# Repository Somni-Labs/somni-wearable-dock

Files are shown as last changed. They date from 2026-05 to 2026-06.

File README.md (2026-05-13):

# Wearable Charging Stand

3D printable unified charging dock for 6 non-Apple wearable devices, with a hidden internal slim 4-port USB-C wall charger and cable management.

## Devices

| Slot | Device | Charger Type | Cradle Style |
|---|---|---|---|
| 1 | Omi Pendant (DevKit 2) | Pogo-pin direct charge | Six-sided diamond pocket (41×40mm) |
| 2 | Ultrahuman Ring Air | USB-C puck dock (~50mm) | Circular cup |
| 3 | Even Realities R1 Ring | NFC magnetic dock (45mm) | Circular cup |
| 4 | Even Realities G2 Glasses | USB-C case (170×75mm) | Rectangular shelf |
| 5 | Omi Developer Edition | Triangle pendant charger | Triangular pocket |
| 6 | Mudra Link Wristband | Proprietary cable | Rectangular pocket |

## Design Features

- **Single AC input** — one cable from the wall to the internal multi-port USB-C charger
- **Hidden cable routing** — channels inside the base route cables from the charger to each cradle
- **Bottom access panel** — removable cover (v2) / removable top tray (v1) to install the charger and manage cables
- **Cradle-per-charger** — each device's existing charger sits in a fitted pocket; cables route through pass-through holes
- **Rubber feet recesses** — stick-on feet for grip and airflow
- **Clean desktop aesthetic** — dark PETG, rounded edges, no visible cables

## Design Files

| File | Description |
|---|---|
| `designs/v1-charging-stand.py` | Two-part snap-fit design (bottom tray + top tray), with iPad slot |
| `designs/v2-charging-stand.py` | Single-piece design with bottom access panel |
| `stl/` | Exported STL files ready for slicing |

## Dimensions

All cradle dimensions are parametric and defined at the top of the design file. After a test print, measure your actual chargers and adjust the `TOL` (tolerance) and individual device dimensions as needed.

**Note:** Some charger dimensions are estimated from product photos since manufacturers don't publish exact specs. Adjust after test fitting:
- Ultrahuman Ring charger: estimated ~50mm diameter puck
- Even R1 charger: measured 45mm diameter × 12mm height dock
- Even G2 case: measured 170×75×30mm
- Omi DevKit 2: measured 41×40×13mm six-sided diamond pendant

## Print Settings

- **Material:** PETG (dark grey/black recommended)
- **Layer height:** 0.2mm
- **Infill:** 20%
- **Walls:** 3 perimeters
- **Supports:** Minimal (cradle cups print fine without)

## Internal USB-C Charger

The stand houses a **slim flat 4-port USB-C wall charger** inside the base, centered under the G2 case shelf. A single AC cable feeds the charger from behind; short USB-C cables route from each output to the cradles through the internal channels.

**Recess dimensions:** 88 × 55 × 17 mm (W × D × H), includes ~3 mm tolerance per side.

### Why a wall charger instead of a USB-C data hub

A passive USB-C "hub" shares a single upstream PD profile across all downstreams, so it can't reliably negotiate independent charging for 6 wearables that each expect their own power profile. A multi-port USB-C wall charger contains independent regulators per port — the architecture each wearable's bundled charger expects.

### Recommended charger class

Look for a **slim flat 4-port USB-C wall charger** at ~30–35 W total with a mix of USB-C and USB-A outputs (typically 1× USB-C PD + 1× USB-C + 2× USB-A). The recess accepts the common "flat brick" form factor (≈83 × 44 × 14 mm).

- ✅ **Fits:** BUDI 34W 4-Port Flat USB-C Wall Charger (slim profile, 20W PD on the primary USB-C port). Any flat 4-port charger within the recess envelope and ≥30 W total works.
- ❌ **Does not fit:** UGREEN Nexode 65W/100W and similar GaN multi-port chargers — they are roughly 65 × 65 × 33 mm because they contain a full wall-AC supply in a cube form factor.
- ❌ **Do not use** a USB-C data hub (CalDigit, Anker thin hubs, etc.) for power splitting — they cannot independently power-deliver to multiple downstreams.

Total wearable load is well under 30 W (each device draws ≤5 W), so a 30–35 W charger has headroom even when everything is on the dock simultaneously.

## Editing

Designs use [CadQuery](https://cadquery.readthedocs.io/) and render via [cadquery-server](https://github.com/robodk/cadquery-server).

```bash
pip install cadquery cadquery-server
cq-server /path/to/designs/
```

## License

MIT

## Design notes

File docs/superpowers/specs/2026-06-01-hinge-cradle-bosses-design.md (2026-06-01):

# Hinge Cradle Bosses for Device Tray

**Date:** 2026-06-01  
**Status:** Approved

## Problem

The tilt plate hinge barrel sockets in `build_device_tray()` are 3.6mm cylindrical cuts positioned at the pocket edge (Y = pocket front face). The pocket cut already removed material from that Y inward, so the sockets only create a ~1.8mm-deep half-pipe scallop in the pocket wall — invisible on a 0.3mm layer-height FDM print and non-functional as a hinge cradle.

The cable notch forward of each pocket further erodes the wall at the same Z range as the sockets, making the problem worse.

## Solution

Replace the cylindrical socket cuts with **raised U-channel cradle bosses** — solid rectangular blocks unioned onto the pocket's front interior wall, with a semicircular channel cut into the top for the hinge barrel to drop into from above.

## Dimensions

### Boss Body
- **Width (X):** `HINGE_BARREL_L + 1.0` = 9.0mm (0.5mm wall each side of 8mm barrel)
- **Depth (Y):** 2.5mm (protrudes into pocket from front wall face)
- **Height (Z):** `HINGE_BARREL_OD + 1.5` = 4.5mm (barrel diameter + 1.5mm retention wall above)

### U-Channel
- **Radius:** `(HINGE_BARREL_OD + HINGE_SOCKET_TOL * 2) / 2` = 1.8mm
- **Open top** — barrel drops in from above
- **Axis:** parallel to X (same as barrel axis)
- **Length:** full boss width (9mm)

### Positioning Per Pocket
- **Y:** pocket front interior wall face (`pocket_center_y - pocket_size/2`), boss extends +Y into the pocket by 2.5mm
- **Z:** bottom of boss at pocket floor level (`STAND_H - CRADLE_DEPTH`), channel center at `pocket_floor + HINGE_BARREL_OD/2 + 0.5`
- **X:** same barrel spacing as existing tilt plates:
  - UH: 20mm apart (±10mm from pocket center X)
  - R1: 8mm apart (±4mm from pocket center X)
  - Omi: 8mm apart (±4mm from pocket center X)

## Assembly

1. Drop tilt plate into pocket — barrels facing front (-Y)
2. Barrels settle into U-channels by gravity
3. Push rod T-head engages captured slot on tilt plate underside
4. Push rod keeps tilt plate seated; U-channel walls prevent barrel pop-out during tilt

## What Changes

- `build_device_tray()`: Remove 6 cylindrical barrel socket cuts, add 6 U-channel cradle boss unions + channel cuts
- Add new constants: `HINGE_BOSS_DEPTH`, `HINGE_BOSS_H`, `HINGE_BOSS_W`
- Re-export device tray STL
- Re-slice device tray

## What Doesn't Change

- Tilt plates (barrel geometry unchanged)
- Push rods
- Top tray
- Bottom tray
- Any other part

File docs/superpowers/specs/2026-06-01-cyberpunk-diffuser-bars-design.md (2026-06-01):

# Cyberpunk Diffuser Bars — Design Spec

## Summary

Add subtle fragmented horizontal light bars recessed into the exterior walls of the bottom tray. Each bar is a shallow recess cut from the outside, leaving a 1.0mm thin-wall diffuser that glows when backlit by the existing U-shaped WS2812B LED strip. The pattern is asymmetric and restrained — cyberpunk but not overwrought.

## Constraints

- **Recess depth:** 1.5mm into the 2.5mm wall (leaves 1.0mm diffuser skin)
- **Bar height:** 3mm tall each
- **Minimum spacing:** 6mm solid wall between adjacent bars
- **Edge clearance:** No cuts within 5mm of top edge (snap clips at Z=50) or bottom edge (floor at Z=0)
- **Usable Z range:** Z=6 to Z=44
- **No new LED routing:** Uses existing U-shaped strip (left, front, right walls)
- **Sharp rectangular edges:** No fillets on bar recesses (cyberpunk aesthetic)
- **Structural integrity:** Narrow bars with wide solid sections between them preserve wall rigidity

## Layout

### Left wall (-X side, ~175mm along Y)

3 bars, staggered heights:

| Bar | Length | Z center | Y offset | Notes |
|-----|---|---|---|---|
| 1 | 60mm | Z=15 | toward front | longest bar, low placement |
| 2 | 25mm | Z=30 | toward front | short, high |
| 3 | 40mm | Z=10 | toward rear  | medium, lowest |

### Right wall (+X side, ~175mm along Y)

3 bars, asymmetric to left wall:

| Bar | Length | Z center | Y offset | Notes |
|-----|---|---|---|---|
| 1 | 45mm | Z=25 | centered | medium, mid-height |
| 2 | 20mm | Z=12 | toward rear  | shortest, low |
| 3 | 55mm | Z=35 | toward front | long, highest |

### Front wall (-Y side, ~240mm along X)

Logo stays at Z=20, center. Two short accent bars flanking it:

| Bar | Length | Z center | X offset | Notes |
|-----|---|---|---|---|
| 1 | 30mm | Z=35 | near left edge  | above logo height |
| 2 | 25mm | Z=12 | near right edge | below logo height |

## Implementation

All cuts happen in `build_bottom_tray()` after the existing LED channel/slot code. Each bar is a `cq.Workplane("XY")` box cut from the exterior wall face inward by 1.5mm, 3mm tall, at the specified length and position.

### Parameters (new constants)

```python
# --- Cyberpunk diffuser bars ---
CYBER_BAR_H = 3            # bar height (Z)
CYBER_BAR_DEPTH = 1.5      # recess depth (leaves 1.0mm diffuser)
CYBER_DIFFUSER_T = 1.0     # remaining wall thickness (diffuser skin)
```

### No changes to

- LED strip channel geometry
- LED exit slots at base
- Backlit logo
- Top tray, device tray, or any other part
- QuinLED / ESP32 / servo mounts
- Snap clips or structural features

## Verification

After export + push + cadquery-server restart, verify:
1. Bars visible as recesses on exterior walls in 3D preview
2. No interference with interior components (LED channel, mounts, wiring grooves)
3. Wall integrity — solid wall remains between and around all bars
4. Logo unobstructed on front wall

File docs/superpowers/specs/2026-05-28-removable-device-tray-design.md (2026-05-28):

# Removable Device Tray

Separate the four front-row wearable device pockets (UH Ring, R1 Ring, Omi pendant, Mudra pole socket) from the top tray body into a standalone drop-in tray. The tray prints right-side up with no supports and drops into a rectangular cutout in the top tray.

## Motivation

The top tray currently contains all four front-row device pockets molded directly into its body. When printed flipped (required because the top tray sits on the bottom tray), these pockets create deep overhangs that require heavy support material, long print times, and risk spaghetti failures. Separating the device zone into its own tray eliminates these problems:

- Device tray prints right-side up -- zero supports
- Top tray flipped print becomes much simpler (single rectangular cutout instead of four complex pockets)
- Device tray can be reprinted independently if devices change
- Faster iteration on pocket geometry without reprinting the entire top tray

## Assembly

6 parts total (was 5):

1. Bottom tray
2. Top tray (with rectangular device tray cutout)
3. **Device tray (new)** -- drops into top tray cutout
4. Mudra pole -- snaps into device tray (was top tray)
5. iPad cover plate
6. iPad back wall

## Device Tray Geometry

### Footprint

The tray spans all four front-row devices:

- **X span**: UH left edge (X = -102) to Mudra shelf right tip (X = +109), plus WALL (2.5mm) on each side = **~220mm wide**
- **Y span**: Front wall inner face (Y = -85) to rear edge of deepest pocket plus margin = **~55mm deep**
- **Z height**: 15mm (from Z = 43 to Z = 58, i.e., SPLIT_Z + LID_FLOOR to STAND_H)

Exact dimensions will be computed from the existing SLOT_POSITIONS, device pocket sizes, and Mudra shelf extent during implementation. The values above are estimates for planning.

### Contents (moved from top tray)

Everything device-specific moves to the device tray:

- **UH Ring pocket** -- square cutout (41x41mm), rounded corners, USB-C front wall notch, floor cable hole, hinge barrel sockets
- **R1 Ring pocket** -- circular cutout (32mm dia), USB-C front wall notch, floor cable hole, hinge barrel sockets
- **Omi pocket** -- six-sided diamond cutout, USB-C front-left notch, floor cable hole, hinge barrel sockets
- **Mudra pole socket** -- rectangular through-hole (20.6x22.6mm) with snap engagement pockets on underside, cable pass-through
- **Push rod slots** -- 4x rectangular through-holes at SERVO_Y for servo actuators
- **Cable pass-through holes** -- USB-C sized holes through tray floor for each device

### Front wall interface

The device tray's front edge butts against the inner face of the top tray's front wall. Cable exit notches in the tray's front edge align with matching slots in the top tray wall, creating a continuous cable path:

```
device pocket --> tray front notch --> top tray front wall slot --> exterior
```

The front wall cable slots for UH, R1, and Omi remain in the top tray's front wall. The device tray has matching open notches on its front edge.

## Top Tray Modifications

### Rectangular cutout

A single rectangular opening replaces all four device pockets. Sized to match the device tray outer dimensions plus 0.3mm clearance per side (SNAP_TOL).

### Perimeter ledge (3-sided)

A 2.5mm wide ledge (WALL thickness) around the cutout at Z = SPLIT_Z + LID_FLOOR (Z = 43). The ledge runs on three sides:

- **Left**: cutout wall
- **Right**: cutout wall  
- **Rear**: cutout wall

The **front side has no ledge** -- the top tray's front wall acts as containment. The tray's front edge sits flush against the wall's inner face.

### Removed geometry

All device pocket cuts, hinge barrel sockets, push rod slots (in the device zone), Mudra socket, and Mudra snap pockets are removed from `build_top_tray()`. The LID_FLOOR remains but gets the device tray cutout instead of individual through-holes for the front-row devices.

### Retained geometry

- Outer shell and walls (including front wall with backlit logo)
- Snap-fit clips for bottom-to-top tray connection
- G2 glasses case pocket (rear row)
- iPad channel, tunnel, blade slot, cover plate rails, front lip
- AC cable pass-through (left wall)
- Spare USB exit (back wall)
- Front wall cable slots (UH, R1, Omi USB-C exits)
- LID_FLOOR (with device tray cutout)
- G2 cable hole, G2 LCD window, iPad cable hole, iPad blade slot re-cuts

## Retention Mechanism

**Drop-in friction fit** -- no clips, no fasteners.

- 0.3mm clearance per side (SNAP_TOL) between tray walls and cutout walls
- Gravity holds the tray down on the ledge
- Front wall contains the tray in -Y
- Cutout walls contain in +/-X and +Y
- Top surface flush at Z = STAND_H (58mm)

If the fit is too loose in practice, small detent bumps (like the iPad wall's IPAD_DETENT_H = 0.6mm) can be added later.

### Mudra pole snap engagement

The Mudra pole's snap hooks currently engage pockets cut into the underside of the top tray at Z = SPLIT_Z - 3mm. With the device tray, the pole snaps into the tray instead. The snap engagement pockets move to the device tray's underside. Since the tray floor is at Z = 43 (DTRAY_FLOOR_Z), the pockets cut upward into the tray body from below. The tray has 15mm of material -- more than enough for the 3mm pocket depth. The cutout ledge in the top tray must have a matching clearance notch so the snap hooks don't collide with the ledge when the tray drops in.

## Printing

### Device tray

- Prints **right-side up** (flat floor on build plate, pockets facing up)
- **No supports needed** -- all pockets are open-top
- **No brim needed** -- solid rectangular base, good adhesion
- Estimated height: 15mm
- Fast print, simple geometry

### Top tray (modified)

- Still prints **flipped** (Z=58 on build plate)
- Dramatically simpler -- one rectangular cutout replaces four complex pocket overhangs
- Support material drops significantly (only G2 pocket + iPad channel overhangs remain)
- Shorter print time

## Export and Slicing

### New function

`build_device_tray()` in `designs/v1-charging-stand.py` -- builds the tray at its assembly position (Z = 43 to Z = 58), exported translated down to Z = 0 for printing.

### Export script

`export_charging_stand.py` gets a new entry:
- `v1-charging-stand-device-tray.stl` / `.step`
- Translated to Z = 0, no flip needed

### Slicer job

New `k8s/slice-device-tray.yaml`:
- No supports, no brim
- 70C bed, 215/220C extruder
- Fan off first 3 layers, 80% max
- sed guard for M106 S255 -> S204
- No support validation check (supports not needed)

### Ghost visualization

The device tray should be included in `build_ghost_components()` or shown as a distinct object in cadquery-server preview for assembly visualization.

## Constants

New constants to add:

```python
# --- Removable device tray ---
DTRAY_TOL = SNAP_TOL          # 0.3mm clearance per side
DTRAY_LEDGE = WALL            # 2.5mm ledge width
DTRAY_FLOOR_Z = SPLIT_Z + LID_FLOOR  # 43mm -- bottom of device tray
```

Width and depth computed dynamically from SLOT_POSITIONS and device dimensions.

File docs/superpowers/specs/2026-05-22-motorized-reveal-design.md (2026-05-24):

# Motorized Wearable Reveal System

**Date**: 2026-05-22
**Status**: Approved

## Overview

Add a motorized "reveal" mechanism to the charging stand: 4x SG90 micro servos in the bottom tray push wearable cradles upward through the top tray at a 30-degree tilt angle when triggered. Replace the small LED driver pocket with a full QuinLED-Dig-Uno WLED controller mount. Update the ESP32 mount for pin-header boards (slot-cradle instead of screw standoffs). Add a VL53L0X proximity sensor for hands-free activation. Add ghost visualization objects for all internal components in the cadquery-server preview.

## 1. SG90 Servo Mounts (4x)

**Servo:** SG90 micro servo (23mm x 12.2mm x 22.7mm body, 32.4mm with mounting ears, 4mm shaft height, ~250mA under load at 5V).

**Orientation:** Upright, shaft pointing UP (+Z). The servo horn connects to a push rod that extends through the top tray floor to tilt the wearable cradle.

**Y position (all 4 servos):** Y = -37mm (fixed row). This places them 12.5mm behind the front-row device centers (Y = -49.5mm) and 5.9mm clear of the charger bay front edge (Y = -25mm).

**X positions (matching device columns):**

| Servo | Device | X (mm) |
|---|---|---|
| 1 | Ultrahuman Ring | -81 |
| 2 | Even R1 | -27 |
| 3 | Omi DevKit | +27 |
| 4 | Mudra Pole | +73 |

**Inter-servo spacing:** 54mm between servos 1-2 and 2-3 (21.6mm gap between ears), 46mm between servos 3-4 (13.6mm gap between ears). All clear.

**Vertical placement:**
- Servo base sits on floor: Z = BASE_H (3mm)
- Servo body top: Z = 3 + 22.7 = 25.7mm
- Servo shaft/horn top: Z = 3 + 26.7 = 29.7mm
- Split plane: Z = 41mm (11.3mm clearance above servo)
- Push rod extends from horn through the 11.3mm gap, through the top tray floor (17mm), to the device cradle

**Mount geometry (per servo):**
- Rectangular pocket in the floor: 34mm x 14mm x 5mm deep (body drops in, ears rest on pocket rim)
- The pocket is 34mm wide to accommodate the 32.4mm ear span + tolerance
- 2x M2 screw posts: 5mm tall, centered on ear screw holes (holes are 27.5mm apart, centered on body)
- Posts are 2.5mm outer diameter with 1mm pilot holes for M2 self-tapping screws
- Open top — servo drops in from above, screws secure the ears

**Clearances:**
- Servo body (12.2mm deep in Y) centered at Y=-37: front edge at Y=-43.1, rear edge at Y=-30.9
- Front-row device pockets start at ~Y=-49.5; smallest gap is Mudra socket rear edge at Y=-38.2 — 4.9mm clear of servo front edge
- Charger bay front at Y=-25 — 5.9mm clear of servo rear edge

## 2. Push Rod Slots (Top Tray)

Each servo needs a slot through the top tray floor for the push rod to pass through and actuate the wearable cradle.

**Slot dimensions:** 4mm wide x 12mm long (oriented along Y), centered at the servo shaft X position, offset from device center by the tilt geometry.

**Push rod geometry:**
- Rigid rod (printed or metal wire), ~2mm diameter
- Connects servo horn to underside of cradle tilt plate
- Rod length: ~28mm (from servo horn at Z=29.7 to cradle floor at Z=STAND_H - cradle_depth)

**Slot positions (in top tray floor, at Z = SPLIT_Z):**

| Slot | X (mm) | Y (mm) | Notes |
|---|---|---|---|
| UH Ring | -81 | -37 | Behind ring pocket |
| R1 Ring | -27 | -37 | Behind disc pocket |
| Omi | +27 | -37 | Behind diamond pocket |
| Mudra | +73 | -37 | Behind pole socket |

## 3. Tilt Mechanism (Front-Row Cradles)

**Concept:** Each front-row cradle (UH Ring, R1, Omi) gets a hinge along its rear edge. The push rod pushes the front edge up, tilting the cradle 30 degrees toward the user. When the servo retracts, the cradle drops back flush.

**Hinge slot:** A narrow gap (0.8mm) cut across the rear edge of each cradle pocket at the floor level. This acts as a living hinge — thin enough to flex but thick enough to survive repeated cycles.

**Tilt angle:** 30 degrees. At 30 degrees with a cradle depth of ~20mm, the front edge rises sin(30) x 20 = 10mm — a subtle but noticeable reveal.

**Mudra pole (servo 4):** The mudra servo pushes the pole straight UP (vertical rise, no tilt). The pole already sits in a through-socket; the push rod lifts it 15mm to present the wristband at a more accessible height. A small collar on the push rod prevents the pole from lifting out completely.

**Implementation note:** The tilt mechanism is a future enhancement that requires careful living-hinge design and push-rod linkage tuning. For the initial build, the servo mounts, push rod slots, and wiring are all installed, but the cradles remain fixed. The servos can be tested independently (horn rotation visible through the slots) before adding the tilt plates in a later iteration.

## 4. QuinLED-Dig-Uno Mount (Replaces Driver Pocket)

**Board:** QuinLED-Dig-Uno v3 (50mm x 50mm PCB, ~30mm tall with components). WLED-compatible ESP8266-based LED controller with onboard level shifting, 2x LED outputs, fused 5V input.

**Location:** Front-right corner of the bottom tray interior (mirrors ESP32 on the front-left). Symmetric layout.

**Position (board center):**
- X = +STAND_W/2 - WALL - 50/2 = +117.5 - 25 = +92.5mm
- Y = -STAND_D/2 + WALL + 50/2 = -85 + 25 = -60mm

**Mount geometry:**
- 4x M2 standoff posts: 3mm diameter, 3mm tall, at QuinLED mounting hole positions (4mm inset from each corner, on a 42mm x 42mm square pattern)
- Two cradle walls: right side (against outer wall) and front side (against front wall), 1.5mm thick, 8mm tall
- Open on left and rear sides for cable access
- The existing cable winding posts in the right-side pocket at Y < -35mm are removed (they overlap the QuinLED footprint). Posts at Y > -35mm remain.

**Power input:** 5V DC from VanBon USB-A port via USB cable. The QuinLED has a screw terminal for 5V input (or can be powered via its own USB port).

**LED strip connection:** QuinLED LED output → WS2812B strip DIN. Wire routes through a floor groove from QuinLED to the right-wall LED channel start.

**Clearances:**
- Board top: 3 + 3 + 30 = 36mm; SPLIT_Z = 41mm — 5mm clearance
- Board left edge at X = 92.5 - 25 = 67.5mm; charger bay right edge at X = 73mm — 5.5mm overlap in X but separated by 35mm in Y (charger at Y=15, QuinLED at Y=-60)
- Mudra servo at X=73, Y=-37: 19.5mm away in X from QuinLED center, no physical overlap

**Replaces:** The old LED driver pocket (22mm x 16mm x 8mm at X=-103, Y=-13) is REMOVED. The QuinLED-Dig-Uno has onboard level shifting, eliminating the need for a separate driver board.

## 5. Updated ESP32 Mount (Pin-Header Slot-Cradle)

**Board:** ESP32-DevKitC V4 with pre-soldered pin headers. Same 55x28mm PCB, but total height ~23mm with headers (~8.5mm pin length below PCB + ~12mm components above).

**Location:** Same front-left corner position (center X=-103, Y=-57).

**Mount change:** Replace the 4 screw standoff posts with a slot-cradle design. The DevKitC V4 doesn't have standard mounting holes; with pin headers, the board rides on the header pins which sit in grooves.

**Slot-cradle geometry:**
- 2 parallel raised rails running along Y (board length direction)
- Rail dimensions: 56mm long (board + 1mm tolerance) x 5mm wide x 10mm tall
- Rail spacing: 25.4mm center-to-center (matching standard 0.1" header pitch for 28mm-wide board)
- Rail X positions: X = -103 +/- 12.7mm = X=-115.7 and X=-90.3
- Each rail has a 3.5mm wide x 8.5mm deep groove on its inner face (the pin headers ride in these grooves)
- Board slides in from the rear (+Y direction) — front end is closed (retaining wall), rear end is open for insertion
- Retaining tab: 2mm tall bump at the front end of each groove to prevent the board from sliding out

**Cradle walls:** Keep the existing left-side and front-side cradle walls (1.5mm thick, 6mm tall) for lateral support above the PCB level.

**USB port access:** Same 12mm x 8mm slot through the front wall, repositioned for the higher board position: Z center = BASE_H + 10 (rail height) + 4mm (USB port center on PCB) = 17mm.

**Clearances:**
- Board top: 3 + 10 + 12 = 25mm; SPLIT_Z = 41mm — 16mm clearance
- Left rail at X=-115.7: inner wall at X=-117.5 — 1.8mm clear (tight but printable)
- Right rail at X=-90.3: charger bay left at X=-73 — 17.2mm clear

## 6. VL53L0X Proximity Sensor Mount

**Sensor:** VL53L0X Time-of-Flight laser ranging module (13mm x 18mm breakout board, I2C, 3.3V, range 30-1200mm). Detects hand approach to trigger the reveal animation.

**Location:** Front wall interior, to the right of the ESP32 mount.

**Position (sensor center):**
- X = _esp_x + ESP32_W/2 + 5 + 9 = -103 + 14.5 + 5 + 9 = -74.5mm
- Y = -STAND_D/2 + WALL + 9 = -85 + 9 = -76mm (against front wall)
- Z = BASE_H + 5 = 8mm (low, pointing forward through front wall)

**Mount geometry:**
- Small clip bracket: two 1.5mm thick x 5mm tall walls on left and right sides of the sensor, spaced 14mm apart (13mm board + 1mm tolerance)
- Sensor drops in from above, held by friction

**Front wall window:**
- Rectangular opening through the front wall: 8mm wide x 6mm tall
- Centered on the sensor's laser emitter/detector position
- Allows the ToF laser to "see" through the wall to detect approaching hands

**Wiring:** I2C (SDA, SCL) + 3.3V + GND from ESP32. 4 wires route through a floor groove from sensor position to ESP32.

## 7. Servo Wiring Channels

**Channel dimensions:** 8mm wide x 4mm deep grooves in the bottom tray floor. Wider than the existing 6mm data wire grooves because servo cables are thicker (3-wire bundles).

**Channel layout:**
- **Main trunk:** Runs along X at Y=-37 (the servo row), connecting all 4 servo positions. Length: from X=-81 to X=+73 = 154mm.
- **ESP32 spur:** From the main trunk at X=-81, turns toward the ESP32 at X=-103, Y=-57. L-shaped: 22mm along X then 20mm along Y.
- **QuinLED spur:** From the main trunk at X=+73, turns toward the QuinLED at X=+92.5, Y=-60. L-shaped: 19.5mm along X then 23mm along Y.

**Wire management clips:** Arch bridges every ~40mm along the main trunk. Same design as the existing cable clips (14mm wide, 8mm tall, 2.5mm thick arch walls) but spaced along the servo wire trunk.

Clip positions on main trunk (Y=-37):
- X = -81 (servo 1)
- X = -54 (midpoint 1-2)
- X = -27 (servo 2)
- X = 0 (midpoint 2-3)
- X = +27 (servo 3)
- X = +50 (midpoint 3-4)
- X = +73 (servo 4)

Note: Some of these may overlap existing front-row cable clips (at Y=-37.5). The implementation should check for overlap and skip duplicates.

## 8. Ghost Visualization Objects

**Pattern:** Follow the somni-humidifier `build_components()` pattern. Create a `build_ghost_components()` function that returns a dict of `{name: (solid, (r, g, b, alpha))}` tuples. Display them with `show_object()` in the build section using translucent colors.

**Components to visualize:**

| Component | Color | RGBA | Shape |
|---|---|---|---|
| ESP32 board | Blue PCB | (0.1, 0.35, 0.7, 0.85) | 55x28x12mm box at mount position |
| QuinLED-Dig-Uno | Green PCB | (0.15, 0.55, 0.15, 0.85) | 50x50x30mm box at mount position |
| SG90 servo x4 | Orange | (0.85, 0.45, 0.1, 0.8) | 23x12.2x22.7mm box + 32.4mm ear plate at each servo position |
| LED strip | Bright green | (0.2, 1.0, 0.3, 0.7) | 10mm x 2mm cross-section, U-shaped path following LED channel |
| VL53L0X sensor | Light blue | (0.3, 0.3, 0.8, 0.85) | 13x18x3mm box at sensor position |
| VanBon charger | Dark gray | (0.3, 0.3, 0.3, 0.5) | 134x68x33mm box in charger bay |
| Servo wires | Yellow | (0.9, 0.85, 0.1, 0.6) | 3mm diameter path following wire channels |

**Display loop (in BUILD AND DISPLAY section):**
```python
ghosts = build_ghost_components()
for comp_name, (comp_solid, comp_color) in ghosts.items():
    show_object(comp_solid, name=f"ghost_{comp_name}",
                options={"color": comp_color})
```

**Implementation:** Each ghost is a simple CadQuery box or extruded shape placed at the component's world-coordinate position. No boolean operations with the tray geometry — these are independent overlay objects for visualization only.

## 9. Constants

New and updated parametric constants:

```python
# --- SG90 micro servo mount ---
SG90_BODY_L = 23          # body length (X)
SG90_BODY_W = 12.2        # body width (Y)
SG90_BODY_H = 22.7        # body height (Z, not including shaft)
SG90_EAR_W = 32.4         # total width with mounting ears
SG90_EAR_T = 2.5          # ear thickness (Z)
SG90_SHAFT_H = 4          # shaft + horn height above body
SG90_SCREW_SPACING = 27.5 # distance between M2 screw holes on ears
SG90_SCREW_D = 2          # M2 screw hole diameter
SERVO_Y = -37             # Y position for all servo mounts
SERVO_POCKET_W = 34       # pocket width (ears + tolerance)
SERVO_POCKET_D = 14       # pocket depth in Y (body + tolerance)
SERVO_POCKET_H = 5        # pocket depth in Z (into floor)
SERVO_POST_H = 5          # screw post height
SERVO_POST_OD = 2.5       # screw post outer diameter
SERVO_PILOT_D = 1.0       # pilot hole for M2 self-tapping

# --- Push rod slots (top tray) ---
PUSH_ROD_SLOT_W = 4       # slot width (X)
PUSH_ROD_SLOT_L = 12      # slot length (Y)

# --- QuinLED-Dig-Uno mount (replaces DRIVER_* constants) ---
QLED_W = 50               # board width (X)
QLED_D = 50               # board depth (Y)
QLED_H = 30               # board height (Z, tallest component)
QLED_STANDOFF_H = 3       # standoff post height
QLED_STANDOFF_D = 3       # standoff post diameter
QLED_MOUNT_INSET = 4      # M2 hole inset from board edge
QLED_MOUNT_PITCH = 42     # M2 hole spacing (50 - 2*4)
QLED_CRADLE_H = 8         # cradle wall height
QLED_CRADLE_T = 1.5       # cradle wall thickness

# --- ESP32 mount (updated for pin headers) ---
ESP32_L = 56              # board length + tolerance (along Y)
ESP32_W = 29              # board width + tolerance (along X)
ESP32_H = 23              # total height with pin headers
ESP32_PIN_H = 8.5         # pin header length below PCB
ESP32_RAIL_H = 10         # slot-cradle rail height
ESP32_RAIL_W = 5          # rail width
ESP32_RAIL_PITCH = 25.4   # center-to-center of rail grooves (0.1" header pitch)
ESP32_GROOVE_W = 3.5      # groove width (2.54mm header + 1mm tolerance)
ESP32_GROOVE_D = 8.5      # groove depth (full pin length)
ESP32_CRADLE_H = 6        # cradle wall height (above rail top)
ESP32_CRADLE_T = 1.5      # cradle wall thickness
ESP32_USB_SLOT_W = 12     # USB port slot width through front wall
ESP32_USB_SLOT_H = 8      # USB port slot height through front wall

# --- VL53L0X proximity sensor ---
PROX_W = 13               # sensor board width (X)
PROX_D = 18               # sensor board depth (Y)
PROX_H = 3                # sensor board height (Z)
PROX_CLIP_H = 5           # clip bracket height
PROX_CLIP_T = 1.5         # clip bracket thickness
PROX_WINDOW_W = 8         # window width through front wall
PROX_WINDOW_H = 6         # window height through front wall

# --- Servo wiring channels ---
SERVO_WIRE_W = 8          # servo wire channel width
SERVO_WIRE_D = 4          # servo wire channel depth
SERVO_CLIP_SPACING = 40   # arch clip spacing along trunk (approximate)
```

## 10. Removed Constants

The following constants are REMOVED (replaced by QuinLED mount):
```python
# REMOVED — replaced by QLED_* constants
# DRIVER_L = 22
# DRIVER_W = 16
# DRIVER_H = 8
# DRIVER_STANDOFF_H = 2
# DRIVER_STANDOFF_D = 2
```

The following ESP32 constants are REMOVED (replaced by slot-cradle design):
```python
# REMOVED — replaced by ESP32_RAIL_*, ESP32_GROOVE_* constants
# ESP32_STANDOFF_H = 2
# ESP32_STANDOFF_D = 3
```

## 11. Print Impact

**Bottom tray changes:**
- Servo pockets: 4x subtractive cuts — slight reduction in print time
- Servo screw posts: 8x small cylinders — negligible material
- QuinLED mount: replaces small driver pocket with larger cradle — slight increase
- ESP32 slot-cradle: replaces standoff posts with rails — roughly equivalent material
- Servo wire channels: subtractive — slight reduction
- Wire arch clips: 7x small arches — negligible
- Proximity sensor bracket: 2 small walls — negligible
- Front wall window: subtractive — negligible
- **Net impact: approximately zero additional print time**

**Top tray changes:**
- 4x push rod slots: subtractive cuts through floor — negligible
- **Net impact: trivially less print time**

## 12. Files Changed

| File | Change |
|---|---|
| `designs/v1-charging-stand.py` | Add servo/QuinLED/sensor constants; replace ESP32 standoffs with slot-cradle and driver pocket with QuinLED mount in `build_bottom_tray()`; add servo mounts, servo wire channels, proximity sensor bracket, push rod slots; add `build_ghost_components()` function; update display section |
| `CLAUDE.md` | Document motorized reveal, QuinLED, updated ESP32 mount, proximity sensor, ghost objects |

## 13. Trigger Mechanism (Software — Future)

The ESP32 handles all trigger logic (not part of the CadQuery geometry, but informs the hardware layout):

- **Proximity:** VL53L0X detects hand within 300mm → triggers reveal animation
- **Button:** Capacitive touch pad on top tray surface (future addition)
- **App:** MQTT/HTTP command from phone via WiFi
- **Schedule:** Time-based (morning routine reveal)

The ESP32 drives all 4 servos via GPIO pins (GPIO 13, 14, 25, 26). PWM signal, no additional driver board needed for SG90 servos.

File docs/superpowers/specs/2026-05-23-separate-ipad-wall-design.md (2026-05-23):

# Separate iPad Back Wall Insert

**Date:** 2026-05-23
**Status:** Approved
**Trigger:** Top tray print cancelled after 10 hours — the 60mm iPad back wall makes the flipped top tray ~77mm tall, consuming massive print time for a simple vertical wall

## Problem

The iPad back wall (`IPAD_BACK_H = 60mm`) is unioned directly onto the top tray. When the top tray is flipped for printing (pocket surface face-down), the wall becomes the tallest feature — 60mm of vertical wall printed first, before the actual tray body even begins. This makes the top tray ~77mm tall on the build plate, adding hours of print time for geometry that is structurally just a flat slab.

## Solution

Extract the iPad back wall into a separate slide-in piece, using tongue-and-groove rails — the same pattern already used for the iPad cover plate. The wall prints flat on its back (4mm tall, ~15 minutes) and slides into the top tray from the side.

### 1. Top Tray Modifications (`build_top_tray()`)

**Remove:** The `ipad_back` union block — the 60mm tall back wall currently built at `Z = STAND_H`, centered at `Y = STAND_D/2 - IPAD_BACK_THICK/2`, width `IPAD_SLOT_W + 10`, thickness `IPAD_BACK_THICK` (4mm).

**Keep:** The front lip (`ipad_lip`) remains on the top tray — 5mm tall, provides iPad retention even without the wall installed.

**Add:** A tongue-and-groove rail along the rear edge of the top tray top surface where the wall base sits.

**Rail groove dimensions:**
- Position: top surface of tray at the rear edge, centered on `Y = STAND_D/2 - IPAD_BACK_THICK/2` (same Y as the old wall)
- Groove width (X): `IPAD_SLOT_W + 10 + 2` (full wall width + exits both sides for slide-in)
- Groove depth (Y): 3mm (into the tray surface)
- Groove height (Z): 3mm (cut down from the top surface)
- Open on both left and right sides — wall slides in from either end
- The groove cut must happen AFTER the `base.edges(">Z").fillet(1.2)` call in `build_top_tray()`, or the fillet will round the groove edges. Alternatively, cut the groove before filleting and ensure the fillet selector excludes groove edges. Simplest: cut the groove after all fillets.

### 2. New `build_ipad_wall()` Function

A standalone flat slab with a tongue tab on its bottom edge.

**Wall body:**
- Width (X): `IPAD_SLOT_W + 10` (same as current — 245mm)
- Height (Z): `IPAD_BACK_H` (60mm)
- Thickness (Y): `IPAD_BACK_THICK` (4mm)
- Built at origin, centered on X, Z=0 at the bottom edge

**Tongue tab:**
- Runs the full width of the wall along the bottom edge
- Tongue depth (Y): 3mm - IPAD_WALL_TOL (= 2.6mm, extends beyond the wall's back face, into the groove)
- Tongue height (Z): 3mm - IPAD_WALL_TOL (= 2.6mm, matches groove height minus clearance)
- Centered on the wall thickness

**Print orientation:** Flat on its back — the 245mm x 60mm face sits on the build plate, making the print only 4mm tall. No rotation needed in the export script.

### 3. Rail Tolerances

Same as the iPad cover plate rails:
- Groove: nominal 3mm deep x 3mm tall
- Tongue: 3mm - IPAD_WALL_TOL deep x 3mm - IPAD_WALL_TOL tall (IPAD_WALL_TOL = 0.4mm, so 2.6mm x 2.6mm)
- This provides 0.2mm clearance per side for a snug slide fit

The global `TOL = 1.0mm` is tuned for device pocket drop-in fit and is too generous for a structural slide joint — it would leave 1mm of slop and wobble. Use a dedicated `IPAD_WALL_TOL = 0.4` constant for the tongue-and-groove fit, giving 0.4mm clearance per side (snug slide, minimal wobble).

### 4. Export Script Updates (`export_charging_stand.py`)

Add iPad wall export:
- `output/v1-charging-stand-ipad-wall.stl` — no rotation needed (prints flat as-built)
- `output/v1-charging-stand-ipad-wall.step` — assembly position for CAD review
- Translate so Z_min = 0 (same as other parts)

Update `exec_globals` to extract the new `ipad_wall` variable.

### 5. cadquery-server Preview

Add `show_object()` call for the iPad wall at its assembly position:
- Translate to `(0, STAND_D/2 - IPAD_BACK_THICK/2, STAND_H)` — same position the old union wall occupied
- Color matching top tray or slightly lighter for visibility

### 6. Ghost Visualization

No ghost needed — the wall is a visible structural part, not an internal component.

### 7. CLAUDE.md Updates

Add to the architecture section:
- iPad wall is now a 5th printable part (bottom tray, top tray, mudra pole, iPad cover plate, iPad wall)

Add to lessons learned:
- Tall vertical walls should be separate parts printed flat, not unioned onto trays that get flipped

## Parts Summary

| Part | Print Orientation | Height on Plate | Estimated Time |
|---|---|---|---|
| iPad back wall (NEW) | Flat (wide face down) | 4mm | ~15 min |
| Top tray (MODIFIED) | Flipped (pockets down) | ~17mm (was ~77mm) | ~4-6h (was 10h+) |

## Files Changed

| File | Change |
|---|---|
| `designs/v1-charging-stand.py` | Remove wall union from `build_top_tray()`, add groove rail, add `build_ipad_wall()`, add `show_object()` call, add `IPAD_WALL_TOL` constant |
| `export_charging_stand.py` | Add iPad wall STL/STEP export |
| `CLAUDE.md` | Update architecture (5 parts), add lesson learned |

## Assembly

1. Print top tray (flipped, ~17mm tall)
2. Print iPad wall (flat, ~4mm tall)
3. Slide iPad wall into rear groove from left or right side
4. iPad leans against wall, front lip prevents forward slide

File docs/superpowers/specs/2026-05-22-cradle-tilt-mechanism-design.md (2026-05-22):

# Cradle Tilt & Mudra Rise Mechanism — Design Spec

**Date:** 2026-05-22
**Status:** Approved
**Depends on:** Motorized reveal infrastructure (servo mounts, push rod slots, wiring channels — all complete)

## 1. Overview

Four mechanical linkages connecting the installed SG90 servos to wearable cradles. Three front-row devices (UH Ring, R1, Omi) get **drop-in tilt plates** with filament pin hinges along their rear edge. The Mudra pole gets a **vertical rise stop** limiting upward travel to 15mm.

All servos, push rod slots, and wiring are already installed. This spec covers only the moving parts: tilt plates, push rods, hinge hardware in the cradle pockets, and the Mudra rise stop.

## 2. Spatial Reference

Key positions (from existing design):

| Device | Cradle Center (X, Y) | Pocket Shape | Pocket Size | Cradle Depth | Push Rod Slot (X, Y) |
|---|---|---|---|---|---|
| UH Ring | (-81.0, -49.5) | Square | 41mm side, 4mm corner R | 10mm | (-81.0, -37.0) |
| R1 Ring | (-27.0, -49.5) | Circle | 32mm diameter | 10mm | (-27.0, -37.0) |
| Omi | (27.0, -49.5) | 6-sided diamond | 30/15mm edges, 3mm vertex R | 15mm | (27.0, -37.0) |
| Mudra | (73.0, -49.5) | Rectangular socket | 20.6x22.6mm through-hole | 16mm (full) | (73.0, -37.0) |

Push rod slots: 4mm (X) x 12mm (Y), centered at SERVO_Y = -37.

Top tray floor: Z = SPLIT_Z = 41mm. Top surface: Z = STAND_H = 58mm.

## 3. Drop-In Tilt Plates (3 parts)

### 3.1 Concept

Each tilt plate is a thin slab matching its cradle pocket footprint. It sits inside the pocket and tilts on a filament pin hinge along its rear edge. When the servo push rod pushes from below, the front edge rises ~30 degrees, presenting the wearable to the user. When the servo retracts, gravity returns the plate to flush.

### 3.2 Plate Dimensions

| Device | Shape | Dimensions | Thickness | Clearance from pocket walls |
|---|---|---|---|---|
| UH Ring | Square, 4mm corner R | 40mm x 40mm | 2mm | 0.5mm per side |
| R1 Ring | Circular | 31mm diameter | 2mm | 0.5mm radial |
| Omi | 6-sided diamond, 3mm vertex R | 29/14.5mm edges | 2mm | 0.5mm per side |

Plates are 1mm smaller than pocket in each dimension (0.5mm clearance per side) to tilt freely without binding.

### 3.3 Pin Hinge System

Each plate has **two cylindrical barrels** on its rear edge (the edge closest to Y=0, i.e., the +Y edge of the pocket):

- **Barrel dimensions:** 8mm long x 3mm OD x 1.75mm ID (bore for filament pin)
- **Barrel count:** 2 per plate, spaced symmetrically ~10mm from each end of the rear edge
- **Barrel orientation:** Axis parallel to X (horizontal, spanning the rear edge)
- **Barrel position:** Centered on the plate thickness (1mm from top/bottom), protruding 1.5mm beyond the rear edge

Matching **barrel sockets** are cut into the cradle pocket rear wall:

- **Socket dimensions:** 8.6mm long x 3.6mm diameter semicircular channel (0.3mm tolerance on each dimension)
- **Socket position:** At pocket floor level (Z = STAND_H - cradle_depth), centered on the wall thickness
- **Socket count:** 2 per pocket, aligned with plate barrels

**Hinge pin:** 1.75mm diameter filament (standard FDM filament), cut to plate width + 4mm. Threads through both barrels and both sockets.

### 3.4 Hinge Line Positions

The hinge is along the rear edge (+Y side) of each cradle pocket. For non-square pockets, the barrels are placed on a flat chord cut across the rear of the plate:

- **UH Ring:** Rear edge is flat (square pocket). Barrels sit directly on the +Y edge at Y = -29.0.
- **R1 Ring:** Circular plate. A 2mm-tall flat chord is cut across the rear at Y = -33.5 (the +Y extent of the 31mm disc). The two barrels mount on this flat. The chord width is ~20mm — enough for two 8mm barrels with spacing.
- **Omi:** Diamond plate. The rearmost vertex is at approximately Y = -30.3. The two barrels mount on the two edges flanking this vertex, angled slightly. Alternatively, a small flat is added at the vertex to mount both barrels on a straight line.

| Device | Hinge Y Position | Distance from Push Rod (Y=-37) | Front Edge Y |
|---|---|---|---|
| UH Ring | -29.0 | 8.0mm | -70.0 |
| R1 Ring | -33.5 | 3.5mm | -65.5 |
| Omi | -30.3 (rearmost vertex) | 6.7mm | -68.7 |

### 3.5 Tilt Geometry

At 30 degree tilt with push rod at Y = -37:

| Device | Rod-to-Hinge Dist | Rise at Rod | Front Edge Dist from Hinge | Rise at Front Edge |
|---|---|---|---|---|
| UH Ring | 8.0mm | 4.6mm | 41.0mm | 23.7mm |
| R1 Ring | 3.5mm | 2.0mm | 32.0mm | 18.5mm |
| Omi | 6.7mm | 3.9mm | 38.4mm | 22.2mm |

The front edge rise of 18-24mm provides a dramatic reveal. The actual tilt angle will be limited by the servo horn travel — full 90 degree horn rotation through the push rod linkage will produce approximately 30 degree plate tilt.

### 3.6 Captured Slot (Push Rod Contact)

On the underside of each tilt plate, centered at the push rod position:

- **Slot channel:** 4.5mm wide (X) x 3mm deep (Y) x 1.5mm tall, running parallel to Y axis
- **Position:** Centered at the point where the push rod slot falls within the plate (X = plate center, Y = -37 relative to world, converted to plate-local coordinates)
- **Purpose:** The push rod T-head sits in this channel, preventing lateral sliding

## 4. Push Rods (4 parts)

### 4.1 Tilt Push Rods (3 — UH Ring, R1, Omi)

- **Cross-section:** 3.5mm x 3.5mm square (fits through 4mm x 12mm slot with clearance)
- **Length:** Variable per device, from servo horn (~Z=30) to tilt plate underside (~Z=48 for UH/R1, ~Z=43 for Omi)
  - UH Ring: ~18mm
  - R1 Ring: ~18mm
  - Omi: ~13mm
- **Top end — T-head:** 6mm wide (X) x 2mm tall (Z) cross-piece, perpendicular to rod axis. Fits in the captured slot on the tilt plate underside. The T-head is wider than the 4mm push rod slot, so it cannot fall through.
- **Bottom end — Horn clip:** Fork with 1.5mm hole, fits over servo horn screw post. Or: flat tab with M2 hole for horn screw.

### 4.2 Mudra Push Rod (1)

- **Cross-section:** 3.5mm x 3.5mm square
- **Length:** ~11mm (from servo horn to pole base)
- **Top end:** Flat pad, 8mm x 8mm x 1.5mm, presses against Mudra pole base
- **Bottom end:** Same horn clip as tilt rods

### 4.3 Push Rod Travel

SG90 servo horn: standard single-arm, ~15mm from center to tip. At 90 degree rotation:
- Vertical displacement at horn tip: 15 x sin(90) = 15mm
- This delivers 15mm of upward push rod travel — sufficient for both the 30 degree tilt and the 15mm Mudra rise.

## 5. Mudra Vertical Rise — Servo-Limited Travel

### 5.1 Concept

The Mudra pole sits in a 20.6mm x 22.6mm through-socket, retained by snap hooks. No socket modification is needed for the rise mechanism. The servo travel itself acts as the rise stop:

- The Mudra push rod has a flat pad (8x8mm) that presses the pole base from below
- Push rod length is sized so that at maximum servo extension (90 degree horn rotation), the pole rises exactly 15mm
- The pole cannot rise further because the servo has reached its mechanical limit
- The pole cannot fall out because the existing snap hooks hold it in the socket
- When the servo retracts, the pole drops back to its rest position (gravity + snap hook engagement)

### 5.2 Why No Socket Modification

Internal shelves or tabs to limit rise travel would block pole insertion — the pole body (20mm) is wider than any gap created by shelves inside the 20.6mm socket. The servo-limited approach avoids this entirely: the servo horn's rotation range mechanically caps the rise at 15mm without any physical stop inside the socket.

## 6. Parts Summary

| Part | Count | Material | Print Orientation | Supports Needed |
|---|---|---|---|---|
| UH Ring tilt plate | 1 | PLA+ | Flat (barrels on top face) | No |
| R1 Ring tilt plate | 1 | PLA+ | Flat (barrels on top face) | No |
| Omi tilt plate | 1 | PLA+ | Flat (barrels on top face) | No |
| Push rod (tilt, UH) | 1 | PLA+ | Vertical | No |
| Push rod (tilt, R1) | 1 | PLA+ | Vertical | No |
| Push rod (tilt, Omi) | 1 | PLA+ | Vertical | No |
| Push rod (Mudra) | 1 | PLA+ | Vertical | No |
| Hinge pins | 3 | 1.75mm filament | N/A (cut from spool) | N/A |

**Modified existing parts:**
- Top tray: Add hinge barrel sockets in 3 cradle pockets (UH Ring, R1, Omi rear walls)
- Mudra pole: No modification needed (snap hooks already constrain it, servo travel limits rise)

## 7. Assembly Order

1. Print all new parts (4 push rods, 3 tilt plates)
2. Cut 3 filament pins from spool (~45mm for UH, ~35mm for R1, ~50mm for Omi)
3. Drop tilt plates into cradle pockets (barrels aligned with sockets in rear wall)
4. Thread filament pins through sockets and barrels to lock plates in place
5. From below: insert push rods through push rod slots (T-heads engage captured slots on plate underside)
6. Attach push rod bottoms to servo horns
7. Insert Mudra pole into socket (snap hooks engage as before)
8. Insert Mudra push rod from below, attach to servo horn

## 8. Changes to Existing Code

### 8.1 Top Tray (`build_top_tray()`)

**Add to each of 3 cradle pocket sections (UH Ring, R1, Omi):**
- Two semicircular barrel sockets cut into the rear wall of each pocket
- Socket position: at pocket floor level, rear (+Y) wall
- Socket dimensions: 8.6mm long x 3.6mm diameter semicircular channel

**No changes to Mudra socket** — servo travel limits rise, snap hooks prevent fallout.

### 8.2 New Functions

- `build_uh_tilt_plate()` — returns the UH Ring tilt plate solid (40x40x2mm square plate + 2 hinge barrels + captured slot)
- `build_r1_tilt_plate()` — returns the R1 Ring tilt plate solid (31mm dia x 2mm disc + 2 hinge barrels + captured slot)
- `build_omi_tilt_plate()` — returns the Omi tilt plate solid (29/14.5mm diamond x 2mm + 2 hinge barrels + captured slot)
- `build_push_rod(length, top_type)` — returns a push rod solid (3.5x3.5mm square rod + T-head or flat pad on top + horn clip on bottom)

### 8.3 Export Script

Add exports for the 3 tilt plates and 4 push rods (7 new STL files). Push rods are small enough to print together on one plate, but export individually for flexibility.

### 8.4 Ghost Visualization

Add translucent ghost overlays for the tilt plates (in tilted position) and push rods (extended position) to visualize the mechanism in cadquery-server.

## 9. Future Considerations

- **Spring return:** If gravity return proves unreliable (e.g., cable drag holds plate up), add a small torsion spring around the hinge pin
- **Damping:** If the plate drops too fast and makes noise, add a small rubber bumper on the pocket floor
- **Tilt angle tuning:** Adjustable by changing push rod length or servo horn arm position — no reprints needed

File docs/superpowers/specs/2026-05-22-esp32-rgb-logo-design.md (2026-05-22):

# ESP32, RGB Underglow, and Backlit Logo

**Date**: 2026-05-22
**Status**: Approved

## Overview

Add three features to the bottom tray: an ESP32 microcontroller mount, a WS2812B RGB LED underglow strip, and a backlit "Somni Labs" logo cut into the front wall. The ESP32 drives the LEDs and can be extended with future functionality. Power comes from spare USB-A ports on the VanBon charger already inside the stand.

## 1. ESP32 Mount

**Board:** ESP32-DevKitC V4 (55mm x 28mm PCB, ~12mm tall with components)

**Location:** Front-left corner of the bottom tray interior, on the floor (Z = BASE_H = 3mm). The board's short edge (28mm, with USB port) faces the front wall. The long edge (55mm) runs along Y (front to back).

**Position (board center):**
- X = -STAND_W/2 + WALL + ESP32_W/2 = -117.5 + 14.5 = -103mm
- Y = -STAND_D/2 + WALL + ESP32_L/2 = -85 + 28 = -57mm
- This places the board in the left side pocket, between the front wall and the charger bay left edge (X = -73). No overlap with cable winding posts (which start at X = -95 inward from the charger edge).

**Mount geometry:**
- 4 standoff posts: 3mm diameter, 2mm tall, positioned at the DevKitC V4 mounting holes (roughly 2mm inset from each corner of the 55x28mm footprint)
- Two cradle walls on the left and front sides: 1.5mm thick, 6mm tall, running the length of each board edge — the board drops in from above and is held snugly against the corner
- Open on the right and rear sides for cable access

**USB port access:**
- Rectangular slot cut through the front wall: 12mm wide x 8mm tall
- Positioned to align with the Micro-USB port on the DevKitC V4 (centered on the board's short edge at X = -103mm, Z = BASE_H + ESP32_STANDOFF_H + 4mm)
- The USB cable plugs in from outside the front wall for power and programming

**Clearances:**
- Board top (3mm floor + 2mm standoffs + 12mm board = 17mm) is well below the tray top (SPLIT_Z = 41mm)
- Board right edge at X = -103 + 14.5 = -88.5mm; charger bay left edge at X = -73mm — 15.5mm clear
- Front-row cable arch clips start at FRONT_START = -81mm (X) — no overlap

## 2. "Somni Labs" Backlit Logo

**Text:** "Somni Labs" in a sans-serif font

**Technique:** Text is recessed into the exterior face of the front wall. The recess cuts through most of the 2.5mm wall thickness, leaving a 0.6mm thin wall (2 print layers at 0.3mm). This thin shell acts as a natural light diffuser — the RGB strip behind it creates a soft, even glow through the letter shapes.

**Dimensions:**
- Text width: ~120mm, centered horizontally on the front wall (X = 0)
- Text height: ~12mm (font size chosen to produce ~12mm cap height)
- Vertical position: centered on the front wall face, roughly Z = 20mm from the base (vertically centered in the 41mm wall height)

**CadQuery implementation:** Use `cq.Workplane.text()` to create the text geometry, then cut it as a recess from the exterior face of the front wall. The cut depth = WALL - 0.6mm = 1.9mm.

## 3. RGB Underglow

**Strip:** WS2812B (NeoPixel) addressable LED strip, 30 LEDs/m density, 10mm wide, 5V DC.

**Path:** U-shaped route along three sides of the bottom tray interior:
- Left side wall (bottom to top in Y): ~170mm
- Front wall (left to right in X): ~235mm
- Right side wall (top to bottom in Y): ~170mm
- Total: ~575mm, approximately 18 LEDs

The strip does NOT run along the back wall — the iPad back wall blocks the view and there's no visual benefit.

**LED channel:**
- Groove cut into the floor of the bottom tray, running along the inner base of the three walls
- Channel dimensions: 12mm wide (10mm strip + 1mm clearance per side) x 4mm deep
- The strip sits in the channel, adhesive side down, held by friction and the channel walls
- Channel is inset 1mm from the inner wall face so light reflects off the wall before exiting

**Light exit slots:**
- Narrow horizontal slot cut through the bottom of the exterior walls on all three sides (front + left + right)
- Slot dimensions: 3mm tall x continuous length matching the interior channel
- Slot bottom edge starts at Z = 1mm (just above the desk surface / rubber feet)
- Light spills downward onto the desk surface, creating the underglow effect

**Logo backlighting:** The front section of the LED channel runs directly behind the "Somni Labs" logo recess. The same LEDs that create the front underglow also backlight the logo. No additional LEDs needed.

## 4. LED Driver / Level Shifter Mount

WS2812B strips run at 5V logic but the ESP32 GPIO outputs 3.3V. A small level shifter board (e.g. SN74HCT125 breakout, ~18mm x 12mm) or a discrete circuit (1x 470-ohm resistor + 1x 1000uF capacitor) is needed between the ESP32 and the strip.

**Location:** Small component pocket next to the ESP32, in the front-left corner. Sits between the ESP32 and the left wall LED channel start.

**Mount geometry:**
- Rectangular pocket: 22mm x 16mm x 8mm deep (fits a small breakout board or a perf board with discrete components)
- 2 standoff posts: 2mm diameter, 2mm tall
- Open top — component drops in, secured with friction or a dab of hot glue

**Position (pocket center):**
- X = ESP32 center X = -103mm (aligned with ESP32)
- Y = ESP32 rear edge + 5mm gap + pocket half-length = -57 + 28 + 5 + 11 = -13mm
- This places it behind the ESP32, still in the left side pocket, clear of the charger bay

## 5. Wiring

**Power:**
- ESP32: powered via Micro-USB cable from VanBon USB-A port (5V, <500mA)
- LED strip: powered from the same USB cable or a second VanBon USB-A port. 18 LEDs at 60mA max each = 1.08A peak (full white). Typical animated patterns draw 300-500mA.

**Data:**
- ESP32 GPIO → level shifter input → level shifter output → LED strip DIN
- Wires route through small floor channels connecting ESP32 → driver pocket → LED channel start

**Floor wiring channels:**
- 6mm wide x 3mm deep groove in the floor connecting:
  1. ESP32 position → left wall LED channel start (for the data wire)
  2. ESP32 position → charger bay area (for the USB power cable from VanBon)
- These are shallow grooves — cables sit in them and the top tray covers everything

## 6. Constants

New parametric constants to add:

```python
# --- ESP32 DevKitC V4 mount ---
ESP32_L = 55 + 1          # board length + tolerance (along Y)
ESP32_W = 28 + 1          # board width + tolerance (along X)
ESP32_H = 12              # board height (tallest component)
ESP32_STANDOFF_H = 2      # standoff post height
ESP32_STANDOFF_D = 3      # standoff post diameter
ESP32_CRADLE_H = 6        # cradle wall height
ESP32_CRADLE_T = 1.5      # cradle wall thickness
ESP32_USB_SLOT_W = 12     # USB port slot width through front wall
ESP32_USB_SLOT_H = 8      # USB port slot height through front wall

# --- RGB LED strip (WS2812B 30/m) ---
LED_CHANNEL_W = 12        # channel width (10mm strip + clearance)
LED_CHANNEL_D = 4         # channel depth into floor
LED_SLOT_H = 3            # light exit slot height on exterior walls
LED_SLOT_Z = 1            # slot bottom edge Z (above desk)

# --- Logo ---
LOGO_TEXT = "Somni Labs"
LOGO_WIDTH = 120          # approximate text span
LOGO_FONT_SIZE = 12       # cap height in mm
LOGO_RECESS_DEPTH = 1.9   # cut depth (WALL - 0.6mm diffuser)
LOGO_Z = 20               # vertical center of text on front wall

# --- LED driver / level shifter mount ---
DRIVER_L = 22             # pocket length (Y)
DRIVER_W = 16             # pocket width (X)
DRIVER_H = 8              # pocket depth (Z)
DRIVER_STANDOFF_H = 2     # standoff height
DRIVER_STANDOFF_D = 2     # standoff diameter
```

## 7. Print Impact

These changes only affect the bottom tray:
- LED channels and wiring grooves are subtractive (cuts) — no added print time
- Logo recess is subtractive — no added print time
- ESP32 standoffs and cradle walls add minimal material (~2g)
- Light exit slots are subtractive — slightly reduce print time
- **Net impact: approximately zero additional print time**

## Files Changed

| File | Change |
|---|---|
| `designs/v1-charging-stand.py` | Add constants, modify `build_bottom_tray()` to add ESP32 mount, LED channels, light exit slots, logo recess, wiring grooves |
| `CLAUDE.md` | Document ESP32 + RGB + logo features |

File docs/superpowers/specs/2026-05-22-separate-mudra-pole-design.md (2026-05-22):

# Separate Mudra Pole Insert

**Date**: 2026-05-22
**Status**: Approved
**Trigger**: Top tray print time jumped from 16h to 37h because support material (48% of filament) is needed for the Mudra shelf overhang when printed flipped

## Problem

The top tray includes the Mudra L-pole (85mm vertical post + 36mm horizontal shelf). When printed flipped (as required for pocket surface quality), the shelf becomes a 36mm horizontal overhang requiring heavy support material — 110 meters of filament and 20+ extra hours of print time. The shelf only supports a light silicone wristband, so the support material is disproportionate to the structural need.

## Solution

Separate the Mudra pole into its own printable part that inserts into a socket on the top tray via snap clips.

### 1. Mudra Pole (new separate part)

The L-pole becomes a standalone piece printed **upright** — no supports needed.

**Geometry (unchanged from current design):**
- Vertical post: `MUDRA_POLE_D` (20mm) x `MUDRA_POLE_W` (22mm) x `MUDRA_POLE_H` (85mm)
- Horizontal shelf: `MUDRA_SHELF_L` (36mm) x `MUDRA_POLE_W` (22mm) x `MUDRA_SHELF_H` (14mm)
- Flush charger pocket in shelf top (open from above, chamfered lip)
- Internal cable channel: vertical cavity through post + horizontal slot connecting to charger bay
- Cable exits through the open bottom face of the pole base

**New: snap clip tabs on the pole base.**
Two cantilever hooks, one on each long side (the 20mm / X-axis faces):
- Hook overhang: `SNAP_HOOK` (1.2mm) — catches underside of top tray floor
- Cantilever height: `SNAP_CLIP_H` (8mm) — enough flex to insert and lock
- Clip width: `SNAP_CLIP_W` (12mm) — centered on each face
- Tolerance: `SNAP_TOL` (0.3mm) per side

The clips extend downward from the pole base. When inserting the pole into the socket, the hooks flex inward, pass through the socket, and snap out to catch the bottom face of the top tray.

**Print orientation:** Upright at Z=0, no rotation. The shelf prints as a horizontal extension off the top of the vertical post — trivial overhang for the slicer since it builds up layer by layer.

### 2. Top Tray Socket (modification)

Replace the built-in pole with a rectangular through-socket.

**Socket dimensions:**
- Width: `MUDRA_POLE_D + SNAP_TOL * 2` (20.6mm in X)
- Depth: `MUDRA_POLE_W + SNAP_TOL * 2` (22.6mm in Y)
- Height: Full tray thickness (`TOP_H` = 17mm) — through-hole

**Snap engagement pockets:**
Small recesses on the bottom face of the top tray around the socket, one on each long side (X-axis faces). These give the snap hooks room to spring out and catch:
- Pocket width: `SNAP_CLIP_W + SNAP_TOL * 2` (12.6mm)
- Pocket depth (into tray bottom face): `SNAP_HOOK` (1.2mm)
- Pocket height: `SNAP_HOOK * 2` (2.4mm)

**Cable pass-through:** The socket is a through-hole, so the cable path is inherently continuous — pole internal cavity → socket hole → bottom tray cavity. The existing `mudra_cable` cut in the top tray base (which cuts a `MUDRA_CABLE_CH_D x MUDRA_CABLE_CH_W` hole through the full height) already provides this. The socket just needs to encompass it.

### 3. Code Changes to `build_top_tray()`

**Remove:** The entire pole-building section:
- Post construction (local coordinates)
- Shelf construction and union
- Charger bay cut
- Chamfer lip loft
- Cable channel cuts (horizontal and vertical)
- `pole.translate()` and `base.union(pole)`
- World-coordinate re-cuts for cable channel continuity

**Add:** Socket cut at the pole position (`mx, my`):
- Rectangular through-hole (`MUDRA_POLE_D + SNAP_TOL*2` x `MUDRA_POLE_W + SNAP_TOL*2` x `TOP_H + 1`)
- Snap hook engagement pockets on the bottom face

**Keep:** The existing `mudra_cable` pass-through cut (already cuts cable channel through the base).

### 4. New `build_mudra_pole()` Function

A new function that builds the pole as a standalone part at the origin:
- Vertical post at origin, extruded upward from Z=0
- Shelf unioned at top
- Charger bay, chamfer lip, cable channels cut (same geometry as current, but built standalone)
- Snap clip tabs added to the base, extending downward (into negative Z, then the export script translates to Z=0)

### 5. Export Updates (`export_charging_stand.py`)

Add a 4th export:
- `output/v1-charging-stand-mudra-pole.stl` — no rotation needed (prints upright)
- `output/v1-charging-stand-mudra-pole.step` — assembly position for CAD review
- Translate so Z_min = 0 (same as other parts)

### 6. Slicer Job Updates (`k8s/slice-all-parts.yaml`)

Add a 4th slice+validate+upload section:
- Input: `v1-charging-stand-mudra-pole.stl` via a new ConfigMap volume (`slicer-stl-input-mudra-pole`)
- Validate: no `--require-supports` (prints upright, no overhangs)
- Upload: `v1-charging-stand-mudra-pole.gcode`

### 7. cadquery-server Preview

The `show_object()` calls at the bottom of the design file need to include the new mudra pole part so it renders in the browser preview. After pushing:
1. `python3 export_charging_stand.py` — verify build succeeds
2. `git commit && git push`
3. `kubectl rollout restart deployment cadquery-server -n utilities` — trigger git-sync
4. Check preview in browser

## Files Changed

| File | Change |
|---|---|
| `designs/v1-charging-stand.py` | Remove pole from `build_top_tray()`, add socket cut, add `build_mudra_pole()` function, add `show_object()` call |
| `export_charging_stand.py` | Add 4th export for mudra pole STL/STEP |
| `k8s/slice-all-parts.yaml` | Add 4th slice+validate+upload section, add ConfigMap volume |
| `CLAUDE.md` | Document the 4-part assembly (bottom tray, top tray, mudra pole, iPad cover) |

## Print Time Impact

| Part | Before (with supports) | After (no supports) |
|---|---|---|
| Top tray | 37h | ~14-16h |
| Mudra pole | (included in top tray) | ~2-3h |
| **Total top half** | **37h** | **~16-19h** |
| Bottom tray | ~15h | ~15h (unchanged) |
| iPad cover | <1h | <1h (unchanged) |

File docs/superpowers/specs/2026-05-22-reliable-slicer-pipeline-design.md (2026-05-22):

# Reliable Slicer Pipeline + Pre-Print Validation

**Date**: 2026-05-22
**Status**: Approved
**Trigger**: Top tray print spaghettified because PrusaSlicer silently ignored support_material setting from sectioned INI file

## Problem

The K8s slicer job (`k8s/slice-all-parts.yaml`) writes a PrusaSlicer profile with `[print:PLA+]`, `[filament:PLA+]`, and `[printer:QIDI_Q2]` section headers. PrusaSlicer's `--load` flag expects a **flat key=value INI** with no section headers. When it encounters section headers, it silently falls back to defaults for all settings in those sections.

This caused two documented failures:
1. **Bed temperature 0C** — PrusaSlicer defaulted to `bed_temperature = 0` instead of the specified 60C. Worked around with `fix_temps()` sed post-processing.
2. **Support material off** — PrusaSlicer defaulted to `support_material = 0` instead of the specified 1. No workaround existed. The top tray (102mm tall, printed flipped with 36mm horizontal Mudra shelf overhang) printed without supports and spaghettified at ~Z=11mm.

The `fix_temps()` function is a band-aid that only patches temperature commands. Other settings (supports, fan speeds, infill density, retraction, etc.) were also silently wrong but happened not to cause visible failures — until now.

## Solution

Three changes that eliminate the root cause and add two defense layers:

### 1. Fix the INI Profile (Root Cause)

Remove section headers from the slicer profile. The INI becomes a flat key=value file with comment-based grouping:

```ini
# --- Print settings ---
layer_height = 0.2
first_layer_height = 0.25
perimeters = 3
top_solid_layers = 5
bottom_solid_layers = 4
fill_density = 20%
fill_pattern = gyroid
external_perimeter_speed = 40
infill_speed = 60
travel_speed = 150
bridge_speed = 25
support_material = 1
support_material_auto = 1
support_material_spacing = 2
support_material_angle = 0
skirts = 2
skirt_distance = 5
brim_width = 0

# --- Filament settings (PLA+) ---
temperature = 215
first_layer_temperature = 220
bed_temperature = 60
first_layer_bed_temperature = 65
fan_always_on = 1
min_fan_speed = 100
max_fan_speed = 100
bridge_fan_speed = 100

# --- Printer settings (QIDI Q2) ---
gcode_flavor = klipper
bed_shape = 0x0,275x0,275x295,0x295
max_print_height = 265
nozzle_diameter = 0.4
retract_length = 0.8
retract_speed = 40
retract_lift = 0.2
start_gcode = G28\nG1 Z5 F5000
end_gcode = END_PRINT
```

The `fix_temps()` function is deleted entirely. PrusaSlicer will emit correct temperature, support, and all other commands natively from the flat INI.

The `sed -i 's/^[[:space:]]*//' "$INI"` line is retained — it strips leading whitespace that YAML heredocs add, which is still necessary.

### 2. Post-Slice Gcode Validator

A `validate_gcode()` bash function runs after each slice, before upload. It parses the generated gcode and asserts critical settings are present and correct.

**Checks:**

| Check | Assertion | How |
|---|---|-----|
| Bed temperature | `M190` or `M140` command present with target >= 55C | grep + awk on gcode |
| Extruder temperature | `M109` or `M104` command present with target >= 210C | grep + awk on gcode |
| Support material | `;TYPE:Support` lines present | grep on gcode |
| Layer count | More than 10 `LAYER_CHANGE` markers (sanity — not empty/corrupt) | grep -c on gcode |
| Coordinate bounds | No G1 X values > 275, no G1 Y values > 295 (all moves, including travel) | grep + awk on gcode |

**Support check nuance:** The support check is conditional. It only applies to parts that need supports (tall parts with overhangs). The validator accepts a `--require-supports` flag. In the slicer job:
- Bottom tray (41mm, no overhangs): no `--require-supports`
- Top tray (102mm, Mudra shelf overhang): `--require-supports`
- iPad cover (2mm flat plate): no `--require-supports`

**Failure behavior:** If any assertion fails, the function prints a clear error message identifying exactly what was wrong and exits non-zero. The slicer job aborts — no gcode is uploaded to Moonraker.

**Location:** Inline bash function in `k8s/slice-all-parts.yaml`, called between the `$SLICER` command and the `curl` upload for each part.

### 3. Pre-Print Check Script

A standalone script at `scripts/pre-print-check.sh` that validates printer readiness before starting a print. Called manually or by future automation.

**Usage:**
```bash
./scripts/pre-print-check.sh <gcode-filename>
# Example:
./scripts/pre-print-check.sh v1-charging-stand-top-tray.gcode
```

**Checks:**

| Check | API Endpoint | Assertion | On Failure |
|---|---|---|---|
| Printer reachable | `GET /printer/info` | HTTP 200, state present | Abort: "Printer unreachable" |
| Printer ready | `GET /printer/info` | `state == "ready"` | Abort: show current state |
| Not already printing | `GET /printer/objects/query?print_stats` | `state == "standby"` | Abort: "Print already active" |
| Filament sensor enabled | `GET /printer/objects/query?filament_switch_sensor...` | `enabled == true` | Auto-fix: run `ENABLE_ALL_SENSOR` macro via `POST /printer/gcode/script`, re-check |
| Filament detected | Same endpoint | `filament_detected == true` | Abort: "Load filament before printing" |
| Gcode file exists | `GET /server/files/metadata?filename=...` | HTTP 200 | Abort: "File not found on printer" |
| Gcode bed temp | Same metadata response | `first_layer_bed_temp > 0` | Abort: "Bed temp is 0 — slicer profile broken" |
| Gcode estimated time | Same metadata response | `estimated_time > 60` | Abort: "Estimated time suspiciously low" |

**Dependencies:** `curl` and `jq` (both available in standard container images and on the host).

**Moonraker base URL:** Hardcoded as `MOONRAKER="http://192.168.1.15:7125"` with an optional `$MOONRAKER_URL` env var override.

**Exit behavior:**
- Exit 0 + "Pre-flight passed — safe to print `<filename>`"
- Exit non-zero + specific error message + remediation instructions

**Filament sensor auto-fix:** When the sensor is disabled (not broken, just turned off — which is the QIDI Q2 default), the script automatically enables it by sending the `ENABLE_ALL_SENSOR` gcode macro, waits 2 seconds, then re-queries. If it's still disabled after the fix attempt, it aborts. This matches the existing CLAUDE.md lesson about the sensor shipping disabled.

### 4. CLAUDE.md Updates

**Remove:** The "PrusaSlicer ignores filament temperatures from combined INI profiles" lesson and its `fix_temps()` documentation. This was a misdiagnosis — the real issue was section headers, not PrusaSlicer behavior.

**Add:** New lesson documenting the flat INI requirement:

> ### PrusaSlicer `--load` requires flat INI — no section headers
>
> PrusaSlicer's `--load` flag expects a flat key=value INI file. If the file contains `[section]` headers (like `[print:PLA+]`), PrusaSlicer silently ignores all settings and falls back to defaults. Use comment-based grouping (`# --- Print settings ---`) instead of section headers.

**Update:** The "Always check the filament sensor before starting a print" lesson to reference the new `scripts/pre-print-check.sh` script as the standard way to do this.

**Add:** Documentation of the post-slice validation and pre-print check as mandatory pipeline steps.

## Files Changed

| File | Change |
|---|---|
| `k8s/slice-all-parts.yaml` | Remove section headers from INI, delete `fix_temps()`, add `validate_gcode()`, call validator after each slice |
| `scripts/pre-print-check.sh` | New file — pre-print validation script |
| `CLAUDE.md` | Update lessons learned, document new pipeline |

## What This Prevents

- Spaghetti from missing supports (the immediate failure)
- Silent wrong temperatures (the previous band-aided failure)
- Silent wrong fan/infill/retraction settings (never caught, possibly affecting print quality)
- Printing with no filament loaded (filament sensor check)
- Printing on a cold bed (metadata check)
- Uploading corrupt/empty gcode (layer count check)
- Out-of-bounds moves (coordinate check)

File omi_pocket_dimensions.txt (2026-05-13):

Omi DevKit 2 Pendant Pocket - Verification Dimensions
====================================================

MEASURED PENDANT (actual device):
  Width:  41.0mm (across widest point)
  Height: 40.0mm (top to bottom)
  Thickness: 13.0mm

POCKET DIMENSIONS (with 1.0mm print tolerance):
  Width:  42.0mm
  Height: 41.0mm
  Depth:  15.0mm (13mm pendant + 2mm margin)

SIX-SIDED DIAMOND VERTICES (mm, from center):
  1. ( -12.6,   20.5)  # top-left
  2. (  12.6,   20.5)  # top-right
  3. (  21.0,    7.5)  # right-upper
  4. (  21.0,   -7.5)  # right-lower
  5. (   0.0,  -20.5)  # bottom point
  6. ( -21.0,   -7.5)  # left-lower
  7. ( -21.0,    7.5)  # left-upper

VERIFICATION MEASUREMENTS:
  Maximum width:    42.0mm (should match 42.0mm)
  Maximum height:   41.0mm (should match 41.0mm)
  Top facet width:  25.2mm (narrow top section)
  Top facet height: 15.0mm (from measurement notes)
  Bottom height:    25.0mm (40mm total - 15mm top)

PRINT VERIFICATION:
1. Print omi_pocket_template.svg at 100% scale (NO SCALING)
2. Cut out the RED outline carefully
3. Test fit your Omi pendant through the cutout
4. Pendant should pass through with slight clearance
5. If too tight/loose, adjust TOL parameter in v1-charging-stand.py

SHAPE VERIFICATION:
- Six-sided diamond (NOT triangle or circle)
- Short top facet tapering to longer bottom point
- Blue dashed line shows pendant outline (41×40mm)
- Red solid line shows pocket outline (with tolerance)

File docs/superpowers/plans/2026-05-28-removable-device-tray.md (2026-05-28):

# Removable Device Tray Implementation Plan

> **For agentic workers:** REQUIRED SUB-SKILL: Use superpowers:subagent-driven-development (recommended) or superpowers:executing-plans to implement this plan task-by-task. Steps use checkbox (`- [ ]`) syntax for tracking.

**Goal:** Separate the four front-row device pockets from the top tray into a standalone drop-in device tray, making both parts easier to print and iterate.

**Architecture:** Add `build_device_tray()` function containing all front-row device geometry (pockets, hinge sockets, push rod slots, Mudra socket). Modify `build_top_tray()` to replace individual pocket cuts with a single rectangular cutout and 3-sided perimeter ledge. Update export script and add slicer job.

**Tech Stack:** CadQuery (Python), PrusaSlicer CLI (K8s Job), Moonraker API

**Spec:** `docs/superpowers/specs/2026-05-28-removable-device-tray-design.md`

---

## File Map

| File | Action | Responsibility |
|---|---|---|
| `designs/v1-charging-stand.py` | Modify | Add `build_device_tray()`, modify `build_top_tray()`, add constants, update build/display section |
| `export_charging_stand.py` | Modify | Add device tray STL/STEP export |
| `k8s/slice-device-tray.yaml` | Create | Slicer job for device tray |
| `CLAUDE.md` | Modify | Update architecture section (6 parts), add lessons learned |

---

### Task 1: Add device tray constants

**Files:**
- Modify: `designs/v1-charging-stand.py:39-52` (constants section, after SNAP_HOOK)

- [ ] **Step 1: Add device tray constants after the snap-fit constants block**

Add these constants after line 52 (`SNAP_HOOK = 1.2`), before the base platform section:

```python
# --- Removable device tray (front-row wearable pockets) ---
# Drop-in friction-fit tray holding UH, R1, Omi pockets + Mudra socket.
# Rests on a 3-sided ledge inside a rectangular cutout in the top tray.
DTRAY_TOL = SNAP_TOL           # 0.3mm clearance per side
DTRAY_LEDGE = WALL             # 2.5mm ledge width for tray to rest on
DTRAY_FLOOR_Z = SPLIT_Z + LID_FLOOR  # 43mm — bottom of device tray
# Width and depth computed dynamically from SLOT_POSITIONS + device sizes
```

- [ ] **Step 2: Verify the file still parses**

Run: `cd /home/curiosity/mounted_drives/obsidian/obsidian/Somni/SomniApps/somni-wearable-dock && python3 -c "exec(open('designs/v1-charging-stand.py').read().replace('from cq_server.ui import ui, show_object', '# stripped').split('show_object')[0])"`

Expected: No errors (constants parse correctly)

- [ ] **Step 3: Commit**

```bash
git add designs/v1-charging-stand.py
git commit -m "feat: add device tray constants (DTRAY_TOL, DTRAY_LEDGE, DTRAY_FLOOR_Z)"
```

---

### Task 2: Create `build_device_tray()` function

**Files:**
- Modify: `designs/v1-charging-stand.py` — add new function after `build_top_tray()` (after line 1755)

This is the largest task. The function builds the device tray body and cuts all four device pockets, cable holes, push rod slots, hinge sockets, and the Mudra pole socket into it.

- [ ] **Step 1: Add the device tray function skeleton with computed dimensions**

Insert after the `return base` at the end of `build_top_tray()` (line 1755), before `build_ipad_cover()`:

```python

# =============================================================================
# BUILD DEVICE TRAY (removable front-row wearable pocket tray)
# =============================================================================

def build_device_tray():
    """Removable device tray: holds UH, R1, Omi pockets + Mudra pole socket.

    Drops into a rectangular cutout in the top tray body, resting on a
    3-sided perimeter ledge (left, right, rear). Front edge butts against
    the top tray's front wall. Flush with top surface at Z=STAND_H.

    Prints right-side up (flat floor on build plate, pockets open upward).
    No supports needed.
    """

    # ── Compute tray footprint from device positions ────────────────────
    # X: from UH left edge to Mudra shelf right tip, plus WALL each side
    _uh_x = SLOT_POSITIONS["uh_ring"][0]
    _mudra_x = SLOT_POSITIONS["mudra"][0]
    _dtray_x_min = _uh_x - UH_SIDE / 2 - WALL          # left edge
    _dtray_x_max = _mudra_x + MUDRA_SHELF_L + WALL      # right edge (shelf tip + wall)
    DTRAY_W = _dtray_x_max - _dtray_x_min               # total width
    _dtray_cx = (_dtray_x_min + _dtray_x_max) / 2       # center X

    # Y: from front wall inner face to rear of deepest pocket + margin
    _dtray_y_min = -STAND_D / 2 + WALL                  # inner face of front wall
    _dtray_y_max = FRONT_ROW_Y + max(UH_SIDE, R1_DIA, 25) / 2 + WALL  # rear edge
    DTRAY_D = _dtray_y_max - _dtray_y_min               # total depth
    _dtray_cy = (_dtray_y_min + _dtray_y_max) / 2       # center Y

    DTRAY_H = STAND_H - DTRAY_FLOOR_Z                   # 15mm (Z=43 to Z=58)

    # ── Shared hinge socket constants ──────────────────────────────────
    _socket_od = HINGE_BARREL_OD + HINGE_SOCKET_TOL * 2  # 3.6mm
    _socket_len = HINGE_BARREL_L + HINGE_SOCKET_TOL * 2  # 8.6mm

    # ── Tray body ───────────────────────────────────────────────────────
    tray = (
        cq.Workplane("XY")
        .workplane(offset=DTRAY_FLOOR_Z)
        .center(_dtray_cx, _dtray_cy)
        .rect(DTRAY_W, DTRAY_D)
        .extrude(DTRAY_H)
    )
```

- [ ] **Step 2: Add UH Ring pocket (CRADLE 1) to the device tray**

Continue the function with the UH pocket, cable notch, floor cable hole, and hinge barrel sockets. This is moved from `build_top_tray()` lines 1128-1180:

```python
    # =====================================================================
    # CRADLE 1: Ultrahuman Ring Air — SQUARE pocket, rounded corners
    # =====================================================================
    ux, uy = SLOT_POSITIONS["uh_ring"]
    uh_pocket = (
        cq.Workplane("XY")
        .workplane(offset=STAND_H - UH_CRADLE_DEPTH)
        .center(ux, uy)
        .rect(UH_SIDE, UH_SIDE)
        .extrude(UH_CRADLE_DEPTH + 1)
    )
    tray = tray.cut(uh_pocket)

    # Front edge cable notch — USB-C exits through tray's front face
    uh_front_slot = (
        cq.Workplane("XY")
        .workplane(offset=STAND_H - UH_CRADLE_DEPTH)
        .center(ux, uy - UH_SIDE / 2 - 5)
        .rect(USBC_HEAD_W, WALL + 12)
        .extrude(USBC_HEAD_H)
    )
    tray = tray.cut(uh_front_slot)

    # Floor pass-through (cable drops to bottom tray)
    uh_cable = (
        cq.Workplane("XY")
        .workplane(offset=DTRAY_FLOOR_Z - 0.5)
        .center(ux, uy - UH_SIDE / 2)
        .rect(USBC_HEAD_W, USBC_HEAD_H)
        .extrude(DTRAY_H + 1)
    )
    tray = tray.cut(uh_cable)

    # Hinge barrel sockets in front (-Y) wall
    _uh_plate_side = UH_SIDE - TILT_CLEARANCE * 2
    _uh_barrel_spacing = _uh_plate_side - 2 * 10
    _uh_front_y = uy - UH_SIDE / 2
    _uh_socket_z = STAND_H - UH_CRADLE_DEPTH

    for x_sign in [-1, 1]:
        _bx = ux + x_sign * _uh_barrel_spacing / 2
        barrel_socket = (
            cq.Workplane("YZ")
            .workplane(offset=_bx - _socket_len / 2)
            .center(_uh_front_y, _uh_socket_z + TILT_PLATE_T / 2)
            .circle(_socket_od / 2)
            .extrude(_socket_len)
        )
        tray = tray.cut(barrel_socket)
```

- [ ] **Step 3: Add R1 Ring pocket (CRADLE 2) to the device tray**

Moved from `build_top_tray()` lines 1188-1238:

```python
    # =====================================================================
    # CRADLE 2: Even R1 Ring — CIRCULAR pocket
    # =====================================================================
    rx, ry = SLOT_POSITIONS["r1_ring"]
    r1_cup = (
        cq.Workplane("XY")
        .workplane(offset=STAND_H - R1_CRADLE_DEPTH)
        .center(rx, ry)
        .circle(R1_DIA / 2)
        .extrude(R1_CRADLE_DEPTH + 1)
    )
    tray = tray.cut(r1_cup)

    # Front edge cable notch
    r1_cable_groove = (
        cq.Workplane("XY")
        .workplane(offset=STAND_H - R1_CRADLE_DEPTH)
        .center(rx, ry - R1_DIA / 2 - 5)
        .rect(USBC_HEAD_W, WALL + 12)
        .extrude(USBC_HEAD_H)
    )
    tray = tray.cut(r1_cable_groove)

    # Floor pass-through
    r1_cable = (
        cq.Workplane("XY")
        .workplane(offset=DTRAY_FLOOR_Z - 0.5)
        .center(rx, ry - R1_DIA / 2)
        .rect(USBC_HEAD_W, USBC_HEAD_H)
        .extrude(DTRAY_H + 1)
    )
    tray = tray.cut(r1_cable)

    # Hinge barrel sockets in front (-Y) wall
    _r1_plate_dia = R1_DIA - TILT_CLEARANCE * 2
    _r1_chord_cut_y = _r1_plate_dia / 2 - 2
    _r1_front_y = ry - _r1_chord_cut_y
    _r1_socket_z = STAND_H - R1_CRADLE_DEPTH
    _r1_barrel_spacing = 8

    for x_sign in [-1, 1]:
        _bx = rx + x_sign * _r1_barrel_spacing / 2
        barrel_socket = (
            cq.Workplane("YZ")
            .workplane(offset=_bx - _socket_len / 2)
            .center(_r1_front_y, _r1_socket_z + TILT_PLATE_T / 2)
            .circle(_socket_od / 2)
            .extrude(_socket_len)
        )
        tray = tray.cut(barrel_socket)
```

- [ ] **Step 4: Add Omi pocket (CRADLE 3) to the device tray**

Moved from `build_top_tray()` lines 1246-1308:

```python
    # =====================================================================
    # CRADLE 3: Omi DevKit 2 — SIX-SIDED DIAMOND pocket
    # =====================================================================
    ox, oy = SLOT_POSITIONS["omi"]
    diamond_pts = six_sided_diamond_points(OMI_LONG_EDGE + TOL * 2, OMI_SHORT_EDGE + TOL * 2)
    diamond_closed = diamond_pts + [diamond_pts[0]]

    omi_pocket = (
        cq.Workplane("XY")
        .workplane(offset=STAND_H - OMI_CRADLE_DEPTH)
        .center(ox, oy)
        .polyline(diamond_closed)
        .close()
        .extrude(OMI_CRADLE_DEPTH + 1)
    )
    omi_pocket = omi_pocket.edges("|Z").fillet(OMI_VERTEX_R)
    tray = tray.cut(omi_pocket)

    # USB-C port notch — front-left of diamond
    _omi_front_y_world = oy + min(p[1] for p in diamond_pts)
    _omi_port_x = ox - 8
    omi_port_slot = (
        cq.Workplane("XY")
        .workplane(offset=STAND_H - OMI_CRADLE_DEPTH)
        .center(_omi_port_x, _omi_front_y_world - 5)
        .rect(USBC_HEAD_W, WALL + 12)
        .extrude(USBC_HEAD_H)
    )
    tray = tray.cut(omi_port_slot)

    # Floor pass-through
    omi_cable = (
        cq.Workplane("XY")
        .workplane(offset=DTRAY_FLOOR_Z - 0.5)
        .center(_omi_port_x, _omi_front_y_world)
        .rect(USBC_HEAD_W, USBC_HEAD_H)
        .extrude(DTRAY_H + 1)
    )
    tray = tray.cut(omi_cable)

    # Hinge barrel sockets in front (-Y) wall
    _omi_pts = six_sided_diamond_points(
        OMI_LONG_EDGE + TOL * 2 - TILT_CLEARANCE * 2,
        OMI_SHORT_EDGE + TOL * 2 - TILT_CLEARANCE * 2
    )
    _omi_front_y_local = min(p[1] for p in _omi_pts)
    _omi_chord_cut_y = _omi_front_y_local + 2
    _omi_front_y = oy + _omi_chord_cut_y
    _omi_socket_z = STAND_H - OMI_CRADLE_DEPTH
    _omi_barrel_spacing = 8

    for x_sign in [-1, 1]:
        _bx = ox + x_sign * _omi_barrel_spacing / 2
        barrel_socket = (
            cq.Workplane("YZ")
            .workplane(offset=_bx - _socket_len / 2)
            .center(_omi_front_y, _omi_socket_z + TILT_PLATE_T / 2)
            .circle(_socket_od / 2)
            .extrude(_socket_len)
        )
        tray = tray.cut(barrel_socket)
```

- [ ] **Step 5: Add Mudra pole socket and snap pockets to the device tray**

Moved from `build_top_tray()` lines 1320-1362. The snap engagement pockets now cut upward into the device tray's underside:

```python
    # =====================================================================
    # CRADLE 4: Mudra Link — pole socket + snap engagement
    # =====================================================================
    mx, my = SLOT_POSITIONS["mudra"]

    # Cable pass-through (full height)
    mudra_cable = (
        cq.Workplane("XY")
        .center(mx, my)
        .rect(MUDRA_CABLE_CH_D, MUDRA_CABLE_CH_W)
        .extrude(STAND_H)
    )
    tray = tray.cut(mudra_cable)

    # Pole socket — through-hole for snap-in pole
    _socket_w = MUDRA_POLE_D + SNAP_TOL * 2   # 20.6mm in X
    _socket_d = MUDRA_POLE_W + SNAP_TOL * 2   # 22.6mm in Y
    mudra_socket = (
        cq.Workplane("XY")
        .workplane(offset=DTRAY_FLOOR_Z - 0.5)
        .center(mx, my)
        .rect(_socket_w, _socket_d)
        .extrude(DTRAY_H + 1)
    )
    tray = tray.cut(mudra_socket)

    # Snap hook engagement pockets on the underside of the tray
    _pocket_w = MUDRA_CLIP_W + SNAP_TOL * 2   # 14.6mm
    _pocket_depth = MUDRA_HOOK                 # 2.0mm
    _pocket_h = MUDRA_HOOK_H + 1              # 3.0mm
    for side_sign in [-1, 1]:
        pocket_x = mx + side_sign * (_socket_w / 2 + _pocket_depth / 2)
        snap_pocket = (
            cq.Workplane("XY")
            .workplane(offset=DTRAY_FLOOR_Z - _pocket_h)
            .center(pocket_x, my)
            .rect(_pocket_depth, _pocket_w)
            .extrude(_pocket_h + 0.5)
        )
        tray = tray.cut(snap_pocket)
```

- [ ] **Step 6: Add push rod slots and generic cable pass-throughs, then return**

```python
    # ── Push rod slots (servo actuator pass-through) ────────────────────
    _push_rod_devices = ["uh_ring", "r1_ring", "omi", "mudra"]
    for name in _push_rod_devices:
        px, py = SLOT_POSITIONS[name]
        push_slot = (
            cq.Workplane("XY")
            .workplane(offset=DTRAY_FLOOR_Z - 0.5)
            .center(px, SERVO_Y)
            .rect(PUSH_ROD_SLOT_W, PUSH_ROD_SLOT_L)
            .extrude(DTRAY_H + 1)
        )
        tray = tray.cut(push_slot)

    # ── Mudra generic cable pass-through (from SLOT_POSITIONS loop) ─────
    # The original top tray cut cable holes for mudra via the generic loop.
    # This is now handled by the mudra_cable cut above, so no extra cut needed.

    return tray
```

- [ ] **Step 7: Commit**

```bash
git add designs/v1-charging-stand.py
git commit -m "feat: add build_device_tray() with all four device cradles"
```

---

### Task 3: Modify `build_top_tray()` — remove device geometry, add cutout and ledge

**Files:**
- Modify: `designs/v1-charging-stand.py:1046-1755` (`build_top_tray()` function)

This task removes the four device cradle sections from `build_top_tray()` and replaces them with a single rectangular cutout and perimeter ledge for the device tray to drop into.

- [ ] **Step 1: Remove CRADLE 1 (UH Ring) from build_top_tray()**

Delete lines 1123-1180 (the entire CRADLE 1 section including the pocket cut, front wall slot, floor pass-through, and hinge barrel sockets). These are now in `build_device_tray()`.

- [ ] **Step 2: Remove CRADLE 2 (R1 Ring) from build_top_tray()**

Delete lines 1182-1238 (the entire CRADLE 2 section). Now in `build_device_tray()`.

- [ ] **Step 3: Remove CRADLE 3 (Omi) from build_top_tray()**

Delete lines 1240-1308 (the entire CRADLE 3 section). Now in `build_device_tray()`.

- [ ] **Step 4: Remove CRADLE 4 (Mudra) from build_top_tray()**

Delete lines 1310-1362 (Mudra cable pass-through, socket, and snap pockets). Now in `build_device_tray()`.

- [ ] **Step 5: Remove front-row push rod slots from build_top_tray()**

The push rod slots at lines 1089-1102 iterate over `["uh_ring", "r1_ring", "omi", "mudra"]`. These are now cut in `build_device_tray()`. Remove this entire block.

- [ ] **Step 6: Remove front-row cable pass-throughs from build_top_tray()**

The cable pass-through loop at lines 1104-1121 cuts holes for each SLOT_POSITIONS entry. Remove the entries that are now handled by the device tray. Keep the loop but only process `"g2_case"` (the only remaining device in the top tray). The `"uh_ring"`, `"r1_ring"`, `"omi"` entries were already skipped with `continue`, and `"mudra"` was handled by the generic branch. Replace the loop with just the G2 cable hole:

```python
    # ── Cable pass-through for G2 (only rear-row device remains) ────────
    gx_cable, gy_cable = SLOT_POSITIONS["g2_case"]
    g2_cable_hole = (
        cq.Workplane("XY")
        .workplane(offset=SPLIT_Z - 0.5)
        .center(gx_cable, gy_cable)
        .rect(USBC_HEAD_W + 2, USBC_HEAD_H + 2)
        .extrude(TOP_H + 1)
    )
    base = base.cut(g2_cable_hole)
```

- [ ] **Step 7: Add device tray rectangular cutout and 3-sided ledge**

Add this section after the snap-fit receiving slots, where the device cradles used to be. This computes the same footprint as `build_device_tray()` and cuts a matching opening:

```python
    # =====================================================================
    # DEVICE TRAY CUTOUT — rectangular opening for drop-in device tray
    # =====================================================================
    # Compute the same footprint as build_device_tray() for a matching cutout.
    _uh_x = SLOT_POSITIONS["uh_ring"][0]
    _mudra_x = SLOT_POSITIONS["mudra"][0]
    _dtray_x_min = _uh_x - UH_SIDE / 2 - WALL
    _dtray_x_max = _mudra_x + MUDRA_SHELF_L + WALL
    _dtray_w = _dtray_x_max - _dtray_x_min
    _dtray_cx = (_dtray_x_min + _dtray_x_max) / 2

    _dtray_y_min = -STAND_D / 2 + WALL
    _dtray_y_max = FRONT_ROW_Y + max(UH_SIDE, R1_DIA, 25) / 2 + WALL
    _dtray_d = _dtray_y_max - _dtray_y_min
    _dtray_cy = (_dtray_y_min + _dtray_y_max) / 2

    # Cut the opening — full height from DTRAY_FLOOR_Z to top, with clearance
    _cutout_w = _dtray_w + DTRAY_TOL * 2   # tray width + clearance
    _cutout_d = _dtray_d + DTRAY_TOL * 2   # tray depth + clearance
    dtray_cutout = (
        cq.Workplane("XY")
        .workplane(offset=DTRAY_FLOOR_Z)
        .center(_dtray_cx, _dtray_cy)
        .rect(_cutout_w, _cutout_d)
        .extrude(STAND_H - DTRAY_FLOOR_Z + 1)
    )
    base = base.cut(dtray_cutout)

    # 3-sided perimeter ledge (left, right, rear) for tray to rest on.
    # The front side has no ledge — the top tray's front wall is containment.
    # The ledge is DTRAY_LEDGE (2.5mm) wide and LID_FLOOR (2mm) tall,
    # sitting at DTRAY_FLOOR_Z - LID_FLOOR (Z=41, same as SPLIT_Z).
    # Actually, the ledge is part of the existing tray body — we just need
    # to make the cutout NOT extend below DTRAY_FLOOR_Z. The LID_FLOOR
    # slab and the tray body below the cutout naturally form the ledge.
    # But we need to extend the cutout on the front side (no ledge there)
    # all the way to the front wall so the tray can butt against it.

    # Extend cutout forward to inner face of front wall (no front ledge)
    _front_extension = (
        cq.Workplane("XY")
        .workplane(offset=DTRAY_FLOOR_Z)
        .center(_dtray_cx, (_dtray_y_min - DTRAY_TOL + (-STAND_D / 2 + WALL)) / 2)
        .rect(_cutout_w, abs(_dtray_y_min - DTRAY_TOL - (-STAND_D / 2 + WALL)) + 1)
        .extrude(STAND_H - DTRAY_FLOOR_Z + 1)
    )
    base = base.cut(_front_extension)

    # Clearance notches for Mudra snap hook engagement pockets.
    # The snap pockets on the device tray underside extend below DTRAY_FLOOR_Z.
    # Cut matching clearance in the ledge area so the tray drops in flush.
    _ms_socket_w = MUDRA_POLE_D + SNAP_TOL * 2
    _ms_pocket_w = MUDRA_CLIP_W + SNAP_TOL * 2
    _ms_pocket_depth = MUDRA_HOOK
    _ms_pocket_h = MUDRA_HOOK_H + 1
    mx_cutout, my_cutout = SLOT_POSITIONS["mudra"]
    for _ms_sign in [-1, 1]:
        _ms_x = mx_cutout + _ms_sign * (_ms_socket_w / 2 + _ms_pocket_depth / 2)
        _ms_clearance = (
            cq.Workplane("XY")
            .workplane(offset=DTRAY_FLOOR_Z - _ms_pocket_h - 0.5)
            .center(_ms_x, my_cutout)
            .rect(_ms_pocket_depth + DTRAY_TOL * 2, _ms_pocket_w + DTRAY_TOL * 2)
            .extrude(_ms_pocket_h + 1)
        )
        base = base.cut(_ms_clearance)
```

- [ ] **Step 8: Update LID_FLOOR re-cuts — remove front-row device holes**

In the "CONTINUOUS LID FLOOR" section (around line 1588+), after the floor is unioned, the following re-cuts are for front-row devices and must be removed since the device tray cutout replaces them:

Remove these re-cuts:
- Push rod slots for `["uh_ring", "r1_ring", "omi", "mudra"]` (lines ~1621-1630)
- Mudra pole socket re-cut (lines ~1632-1642)
- Mudra cable hole re-cut (lines ~1644-1652)
- Mudra snap hook engagement pockets re-cut (lines ~1654-1667)
- UH cable hole re-cut (lines ~1673-1682)
- R1 cable hole re-cut (lines ~1684-1693)
- Omi cable hole re-cut (lines ~1695-1707)

Keep these re-cuts (rear-row devices, still in top tray):
- G2 cable hole (lines ~1709-1718)
- G2 LCD viewing window (lines ~1720-1729)
- iPad cable vertical hole (lines ~1731-1740)
- iPad blade slot (lines ~1742-1753)

The device tray cutout itself will replace all the individual front-row floor holes. Add a single re-cut for the device tray opening through the LID_FLOOR:

```python
    # Device tray cutout — re-cut through LID_FLOOR
    _floor_dtray_cutout = (
        cq.Workplane("XY")
        .workplane(offset=SPLIT_Z)
        .center(_dtray_cx, _dtray_cy)
        .rect(_cutout_w, _cutout_d)
        .extrude(LID_FLOOR + 0.5)
    )
    base = base.cut(_floor_dtray_cutout)
```

Note: `_dtray_cx`, `_dtray_cy`, `_cutout_w`, `_cutout_d` are already computed earlier in the function from Step 7. Make sure these variables are in scope (they are, since they're defined in the same function body).

- [ ] **Step 9: Keep front wall cable slots**

The USB-C cable exit slots in the top tray's front wall for UH, R1, and Omi must remain. These are NOT part of the device cradle cuts — they're wall pass-throughs that the device tray's front-edge notches align with. However, looking at the original code, the front wall slots were cut as part of each cradle section (e.g., `uh_front_slot` cuts deep enough to "visibly breach front wall").

Since the device tray's front edge now butts against the front wall's inner face, the cable must pass through BOTH the device tray's front notch AND the top tray's front wall. The device tray already has front notches (from Step 2-4). The top tray needs matching wall slots.

Add these front wall cable slots to `build_top_tray()`, after the device tray cutout:

```python
    # ── Front wall cable slots (matching device tray front-edge notches) ──
    # These pass through the top tray's front wall so cables from device
    # pockets can exit to the exterior. The device tray has matching open
    # notches on its front edge that align with these.

    # UH cable slot
    _uh_wall_x = SLOT_POSITIONS["uh_ring"][0]
    uh_wall_slot = (
        cq.Workplane("XY")
        .workplane(offset=STAND_H - UH_CRADLE_DEPTH)
        .center(_uh_wall_x, -STAND_D / 2)
        .rect(USBC_HEAD_W, WALL * 2 + 2)
        .extrude(USBC_HEAD_H)
    )
    base = base.cut(uh_wall_slot)

    # R1 cable slot
    _r1_wall_x = SLOT_POSITIONS["r1_ring"][0]
    r1_wall_slot = (
        cq.Workplane("XY")
        .workplane(offset=STAND_H - R1_CRADLE_DEPTH)
        .center(_r1_wall_x, -STAND_D / 2)
        .rect(USBC_HEAD_W, WALL * 2 + 2)
        .extrude(USBC_HEAD_H)
    )
    base = base.cut(r1_wall_slot)

    # Omi cable slot
    _omi_wall_x = SLOT_POSITIONS["omi"][0] - 8  # offset left, matching pocket
    omi_wall_slot = (
        cq.Workplane("XY")
        .workplane(offset=STAND_H - OMI_CRADLE_DEPTH)
        .center(_omi_wall_x, -STAND_D / 2)
        .rect(USBC_HEAD_W, WALL * 2 + 2)
        .extrude(USBC_HEAD_H)
    )
    base = base.cut(omi_wall_slot)
```

- [ ] **Step 10: Commit**

```bash
git add designs/v1-charging-stand.py
git commit -m "refactor: replace device pockets in top tray with rectangular cutout and ledge"
```

---

### Task 4: Update build/display section and export script

**Files:**
- Modify: `designs/v1-charging-stand.py:2493-2581` (build and display section)
- Modify: `export_charging_stand.py`

- [ ] **Step 1: Add device tray build + show_object call**

In the BUILD AND DISPLAY section (line ~2497), after `top_tray = build_top_tray()`, add:

```python
device_tray = build_device_tray()
```

After the `show_object(top_tray, ...)` call (line ~2506), add:

```python
show_object(device_tray, name="device_tray",
            options={"color": (0.25, 0.25, 0.27, 0.95)})
```

- [ ] **Step 2: Update export script — add device_tray export**

In `export_charging_stand.py`, after the line `mudra_pole = exec_globals.get('mudra_pole')` (line 45), add:

```python
        device_tray = exec_globals.get('device_tray')
```

After the mudra pole translation block (around line 94), add:

```python
    # Device tray — translate to Z=0 for printing (no flip needed)
    if device_tray:
        dtray_bb = device_tray.val().BoundingBox()
        dtray_print = device_tray.translate((0, 0, -dtray_bb.zmin))
        print(f"   Device tray: translated Z by {-dtray_bb.zmin:+.1f}mm (was Z={dtray_bb.zmin:.1f})")
```

After the mudra pole STL/STEP export block (around line 171), add:

```python
        # Device tray — drop-in wearable pocket tray
        if device_tray:
            dtray_stl_path = output_dir / "v1-charging-stand-device-tray.stl"
            cq.exporters.export(dtray_print, str(dtray_stl_path))
            print(f"✅ {dtray_stl_path} - Device tray (drop-in, prints right-side up)")

            dtray_step_path = output_dir / "v1-charging-stand-device-tray.step"
            cq.exporters.export(device_tray, str(dtray_step_path))
            print(f"✅ {dtray_step_path} - Device tray STEP (assembly position)")
```

- [ ] **Step 3: Commit**

```bash
git add designs/v1-charging-stand.py export_charging_stand.py
git commit -m "feat: add device tray to build/display section and export script"
```

---
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

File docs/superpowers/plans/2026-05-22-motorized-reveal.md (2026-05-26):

# Motorized Wearable Reveal System Implementation Plan

> **For agentic workers:** REQUIRED SUB-SKILL: Use superpowers:subagent-driven-development (recommended) or superpowers:executing-plans to implement this plan task-by-task. Steps use checkbox (`- [x]`) syntax for tracking.

**Goal:** Add 4x SG90 servo mounts, QuinLED-Dig-Uno controller, updated ESP32 slot-cradle mount, proximity sensor, servo wiring channels, push rod slots, and ghost visualization objects to the charging stand CAD model.

**Architecture:** All geometry changes happen in the single `designs/v1-charging-stand.py` file — constants section, `build_bottom_tray()`, `build_top_tray()`, and a new `build_ghost_components()` function. Old constants and geometry (driver pocket, ESP32 standoffs) are replaced inline. The export script (`export_charging_stand.py`) needs no changes since it exports the same 4 printable parts.

**Tech Stack:** CadQuery (Python), cadquery-server for live preview

---

## File Structure

| File | Responsibility | Action |
|---|---|---|
| `designs/v1-charging-stand.py` | All CadQuery geometry + constants | Modify: update constants (lines 134-162), modify `build_bottom_tray()` (lines 513-708), modify cable post loop (lines 418-456), add servo mounts + wiring, modify `build_top_tray()` (add push rod slots), add `build_ghost_components()`, update display section |
| `CLAUDE.md` | Project documentation | Modify: add motorized reveal, QuinLED, sensor, ghost objects to Architecture section |

---

### Task 1: Update Constants — Remove Old, Add New

**Files:**
- Modify: `designs/v1-charging-stand.py:134-162`

This task replaces the old ESP32 standoff + driver pocket constants with new servo, QuinLED, slot-cradle ESP32, proximity sensor, and wiring channel constants. The old constants (`DRIVER_L`, `DRIVER_W`, `DRIVER_H`, `DRIVER_STANDOFF_H`, `DRIVER_STANDOFF_D`, `ESP32_STANDOFF_H`, `ESP32_STANDOFF_D`) are deleted. `ESP32_L`, `ESP32_W`, and `ESP32_H` are updated to new values for the pin-header board.

- [x] **Step 1: Replace the ESP32 constants block**

In `designs/v1-charging-stand.py`, find the block at lines 134-143:

```python
# --- ESP32 DevKitC V4 mount ---
ESP32_L = 55 + 1          # board length + tolerance (along Y)
ESP32_W = 28 + 1          # board width + tolerance (along X)
ESP32_H = 12              # board height (tallest component)
ESP32_STANDOFF_H = 2      # standoff post height
ESP32_STANDOFF_D = 3      # standoff post diameter
ESP32_CRADLE_H = 6        # cradle wall height
ESP32_CRADLE_T = 1.5      # cradle wall thickness
ESP32_USB_SLOT_W = 12     # USB port slot width through front wall
ESP32_USB_SLOT_H = 8      # USB port slot height through front wall
```

Replace with:

```python
# --- ESP32 DevKitC V4 mount (pin-header slot-cradle) ---
ESP32_L = 56              # board length + tolerance (along Y)
ESP32_W = 29              # board width + tolerance (along X)
ESP32_H = 23              # total height with pin headers
ESP32_PIN_H = 8.5         # pin header length below PCB
ESP32_RAIL_H = 10         # slot-cradle rail height
ESP32_RAIL_W = 5          # rail width
ESP32_RAIL_PITCH = 25.4   # center-to-center of rail grooves (0.1" header pitch)
ESP32_GROOVE_W = 3.5      # groove width (2.54mm header + 1mm tolerance)
ESP32_GROOVE_D = 8.5      # groove depth (full pin length)
ESP32_CRADLE_H = 6        # cradle wall height (above rail top)
ESP32_CRADLE_T = 1.5      # cradle wall thickness
ESP32_USB_SLOT_W = 12     # USB port slot width through front wall
ESP32_USB_SLOT_H = 8      # USB port slot height through front wall
```

- [x] **Step 2: Replace the driver pocket constants with QuinLED + new feature constants**

Find the block at lines 157-162:

```python
# --- LED driver / level shifter mount ---
DRIVER_L = 22             # pocket length (Y)
DRIVER_W = 16             # pocket width (X)
DRIVER_H = 8              # pocket depth (Z)
DRIVER_STANDOFF_H = 2     # standoff height
DRIVER_STANDOFF_D = 2     # standoff diameter
```

Replace with:

```python
# --- QuinLED-Dig-Uno mount (WLED controller, replaces old driver pocket) ---
QLED_W = 50               # board width (X)
QLED_D = 50               # board depth (Y)
QLED_H = 30               # board height (Z, tallest component)
QLED_STANDOFF_H = 3       # standoff post height
QLED_STANDOFF_D = 3       # standoff post diameter
QLED_MOUNT_INSET = 4      # M2 hole inset from board edge
QLED_MOUNT_PITCH = 42     # M2 hole spacing (50 - 2*4)
QLED_CRADLE_H = 8         # cradle wall height
QLED_CRADLE_T = 1.5       # cradle wall thickness

# --- SG90 micro servo mount (4x) ---
SG90_BODY_L = 23          # body length (X)
SG90_BODY_W = 12.2        # body width (Y)
SG90_BODY_H = 22.7        # body height (Z, not including shaft)
SG90_EAR_W = 32.4         # total width with mounting ears
SG90_EAR_T = 2.5          # ear thickness (Z)
SG90_SHAFT_H = 4          # shaft + horn height above body
SG90_SCREW_SPACING = 27.5 # distance between M2 screw holes on ears
SG90_SCREW_D = 2          # M2 screw hole diameter
SERVO_Y = -37             # Y position for all servo mounts
SERVO_POCKET_W = 34       # pocket width (ears + tolerance)
SERVO_POCKET_D = 14       # pocket depth in Y (body + tolerance)
SERVO_POCKET_H = 5        # pocket depth in Z (into floor)
SERVO_POST_H = 5          # screw post height
SERVO_POST_OD = 2.5       # screw post outer diameter
SERVO_PILOT_D = 1.0       # pilot hole for M2 self-tapping
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

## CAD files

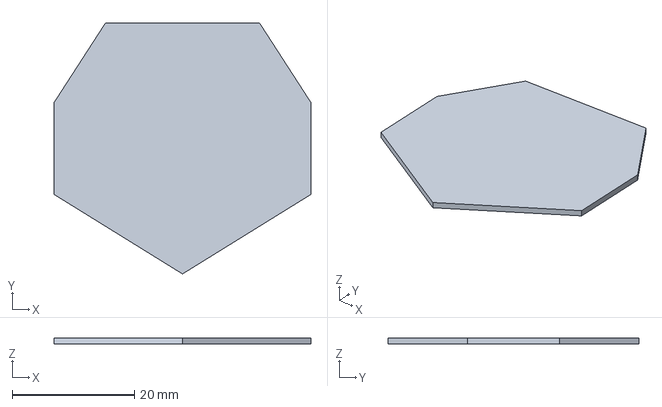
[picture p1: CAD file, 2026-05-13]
omi_pocket_template.step
42.0 x 41.0 x 1.00 mm

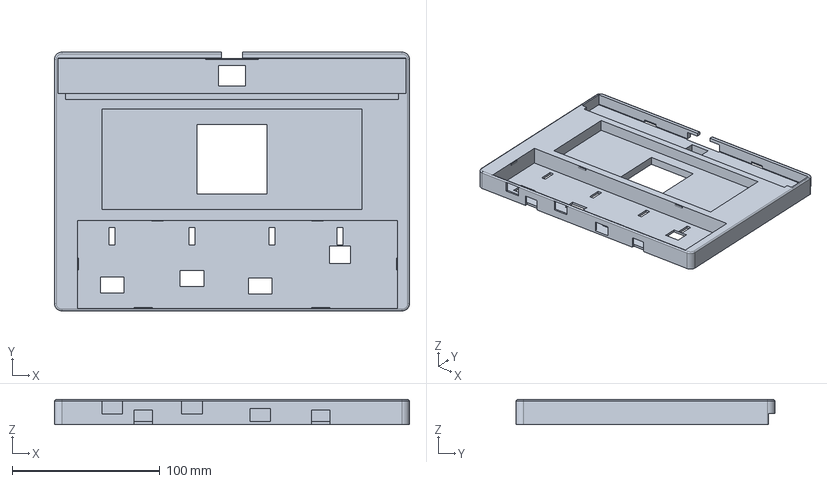
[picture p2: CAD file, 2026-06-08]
output/v1-charging-stand-top-tray.step
240.0 x 175.0 x 17.0 mm

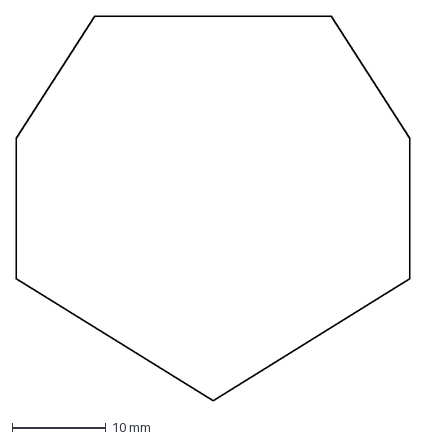
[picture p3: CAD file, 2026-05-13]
omi_pocket_2d.dxf
42.0 x 41.0 mm

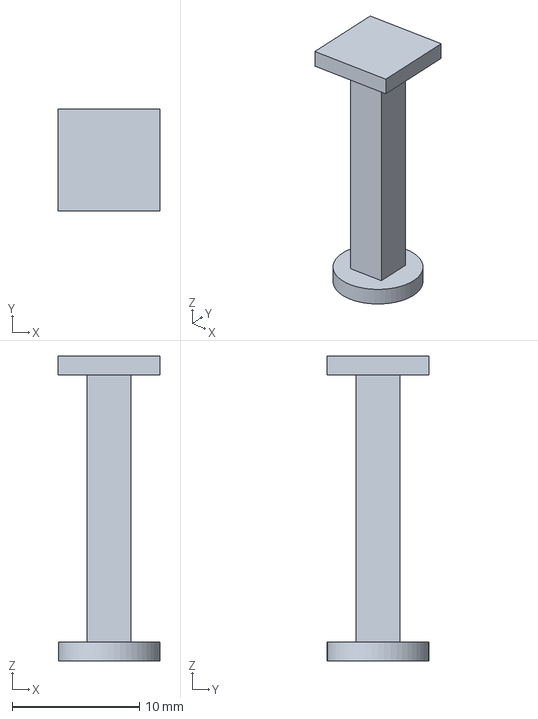
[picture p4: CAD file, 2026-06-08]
output/v1-charging-stand-push-rod-mudra.step
8.00 x 8.00 x 24.0 mm

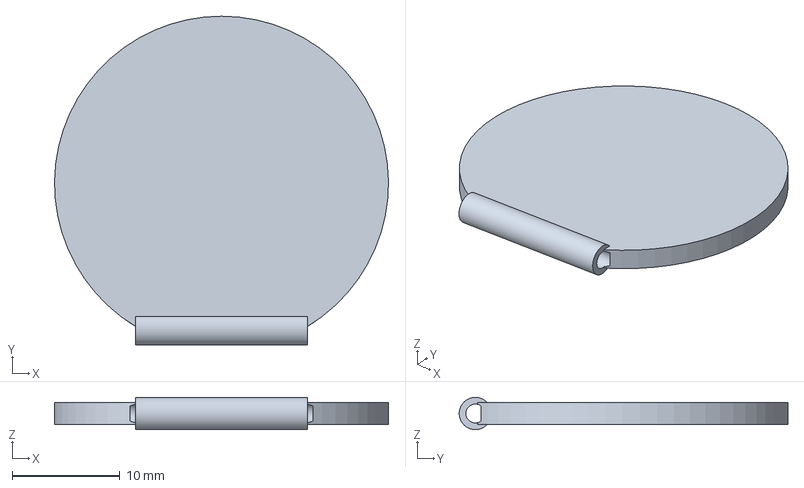
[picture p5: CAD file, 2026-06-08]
output/v1-charging-stand-tilt-plate-r1.step
31.0 x 30.5 x 3.00 mm

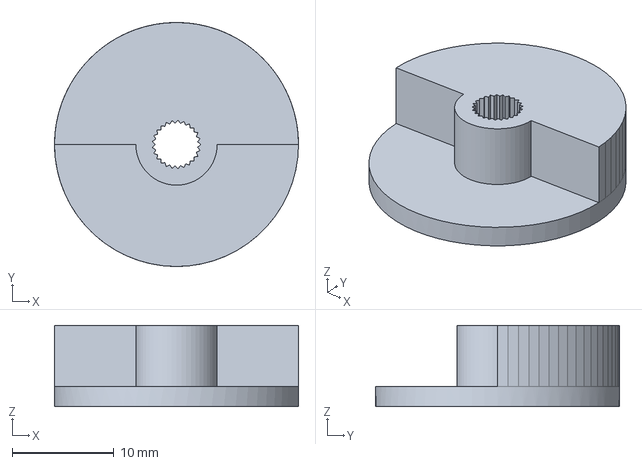
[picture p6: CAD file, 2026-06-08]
output/v1-charging-stand-servo-cam.step
24.0 x 24.0 x 8.00 mm

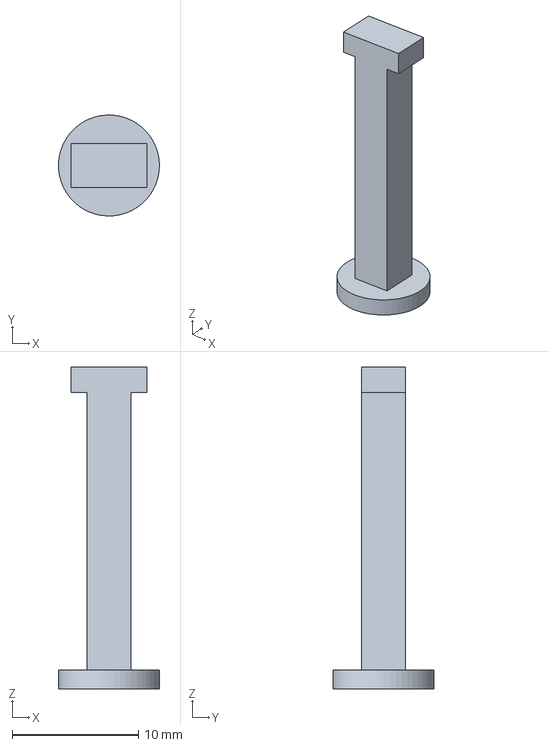
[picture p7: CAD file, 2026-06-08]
output/v1-charging-stand-push-rod-omi.step
7.99 x 8.00 x 25.5 mm

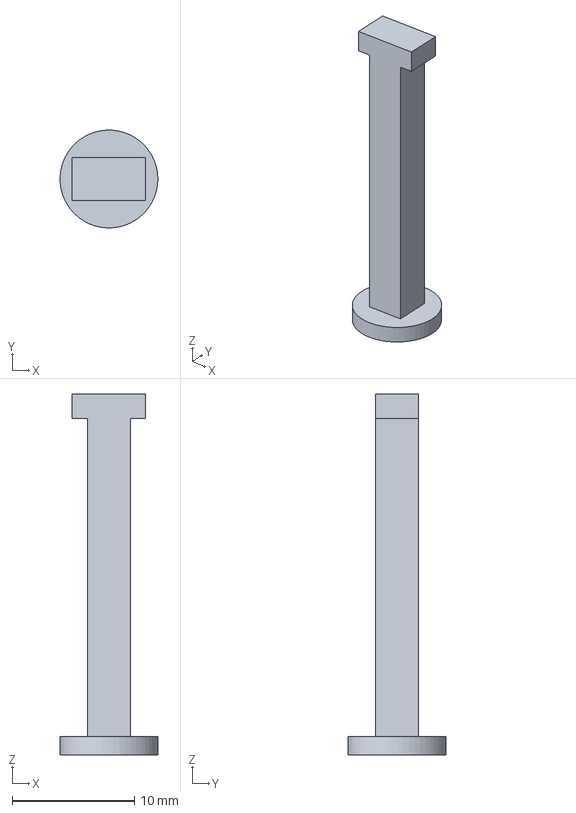
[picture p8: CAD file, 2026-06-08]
output/v1-charging-stand-push-rod-uh_ring.step
7.99 x 8.00 x 29.5 mm

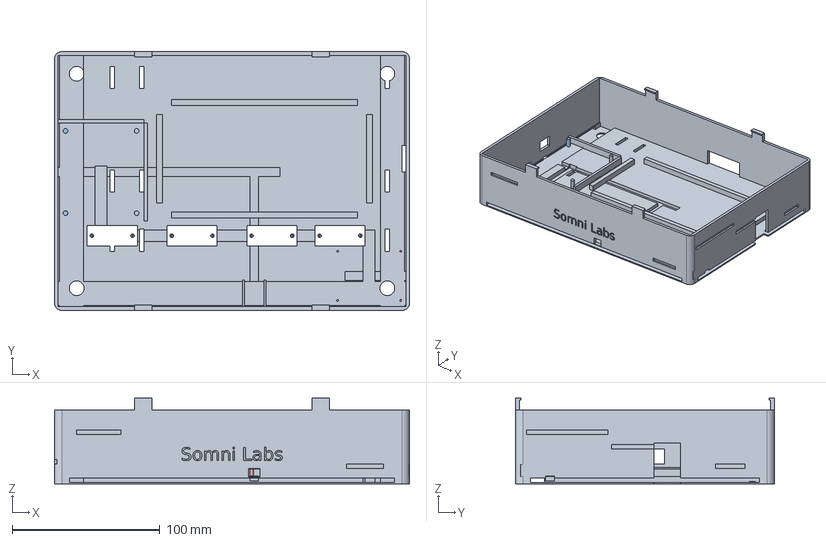
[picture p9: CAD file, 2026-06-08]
output/v1-charging-stand-bottom-tray.step
240.0 x 175.0 x 58.0 mm

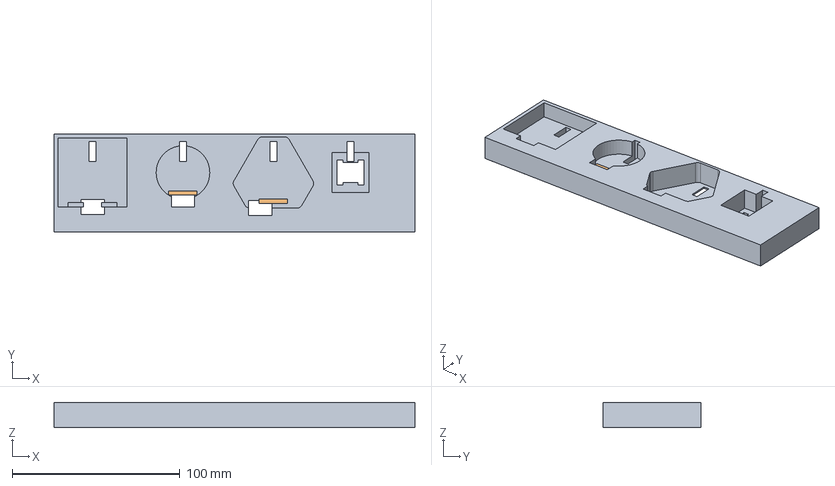
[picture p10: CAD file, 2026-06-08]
output/v1-charging-stand-device-tray.step
215.5 x 58.5 x 15.0 mm

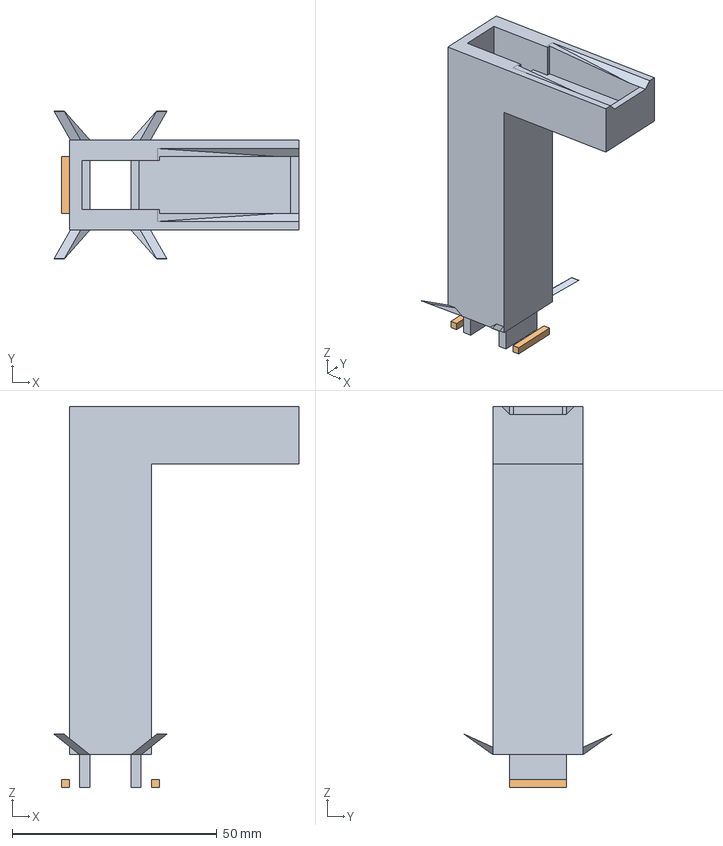
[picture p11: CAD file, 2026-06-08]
output/v1-charging-stand-mudra-pole.step
59.8 x 36.1 x 93.0 mm

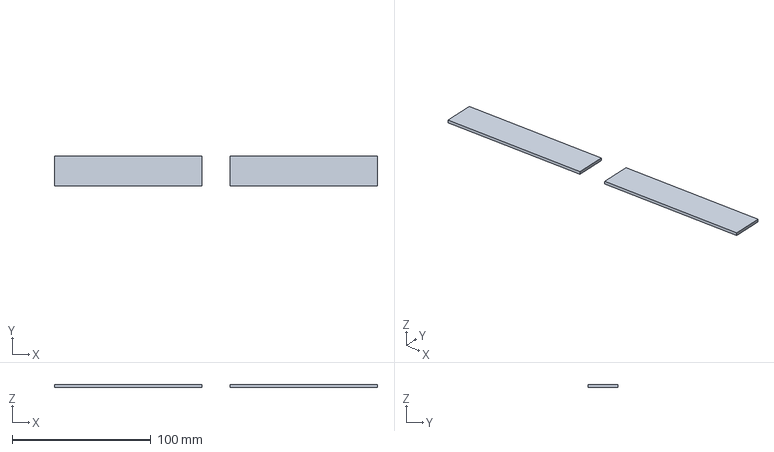
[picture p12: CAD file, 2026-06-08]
output/v1-charging-stand-ipad-cover.step
233.0 x 22.0 x 2.00 mm

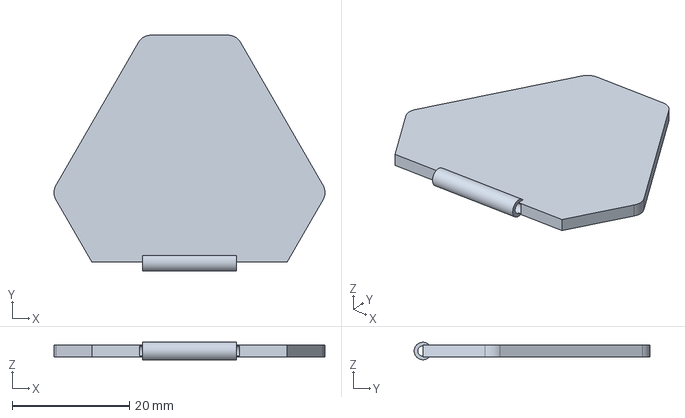
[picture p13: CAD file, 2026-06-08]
output/v1-charging-stand-tilt-plate-omi.step
46.2 x 40.2 x 3.00 mm

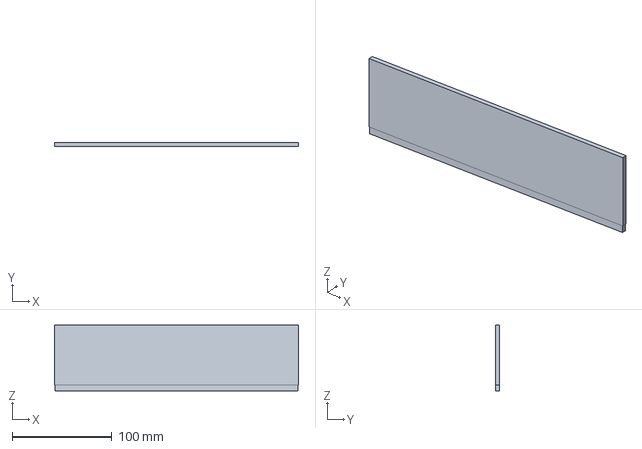
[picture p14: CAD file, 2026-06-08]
output/v1-charging-stand-ipad-wall.step
245.0 x 4.00 x 66.0 mm

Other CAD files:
omi_pocket_profile.step
output/v1-charging-stand-push-rod-r1_ring.step
output/v1-charging-stand-tilt-plate-uh.step
omi_pocket_profile.dxf
output/v1-charging-stand-bottom-tray.stl
output/v1-charging-stand-device-tray.stl
output/v1-charging-stand-ipad-cover.stl
output/v1-charging-stand-ipad-wall.stl
output/v1-charging-stand-mudra-pole.stl
output/v1-charging-stand-push-rod-mudra.stl
output/v1-charging-stand-push-rod-omi.stl
output/v1-charging-stand-push-rod-r1_ring.stl
output/v1-charging-stand-push-rod-uh_ring.stl
output/v1-charging-stand-servo-cam.stl
output/v1-charging-stand-tilt-plate-omi.stl
output/v1-charging-stand-tilt-plate-r1.stl
output/v1-charging-stand-tilt-plate-uh.stl
output/v1-charging-stand-top-tray.stl

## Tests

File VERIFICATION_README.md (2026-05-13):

# Omi DevKit 2 Pocket Verification Guide

## Quick Test (Recommended)

**Print and cut test:**
1. Print `omi_pocket_template.svg` at **100% scale** (NO scaling!)
2. Cut out the **RED outline** carefully with scissors or craft knife
3. Test fit your Omi DevKit 2 pendant through the cutout
4. ✅ **Pass**: Pendant slides through with slight clearance  
5. ❌ **Fail**: Adjust `TOL` parameter in `designs/v1-charging-stand.py`

## Files Generated

| File | Purpose | How to Use |
|---|---|---|
| `omi_pocket_template.svg` | 📄 **Print template** | Print 1:1, cut out RED line, test fit |
| `omi_pocket_dimensions.txt` | 📋 Dimensions reference | Check measurements vs your calipers |
| `omi_pocket_2d.dxf` | 🔧 CAD import (precise) | Open in CAD software for verification |
| `omi_pocket_template.step` | 🔧 3D CAD model | Import into Fusion 360, SolidWorks, etc. |
| `omi_pocket_coordinates.csv` | 📊 Coordinate data | Manual verification, spreadsheet analysis |
| `omi_pocket_outline.gcode` | ⚙️ CNC template cut | Run on CNC router (1mm deep template) |

## Verification Checklist

- [ ] **Shape**: Six-sided diamond (NOT triangle or circle)  
- [ ] **Top facet**: ~25mm wide, narrow section at top
- [ ] **Bottom point**: Single point at bottom (NOT rounded)
- [ ] **Width**: 42mm max (41mm pendant + 1mm tolerance)
- [ ] **Height**: 41mm max (40mm pendant + 1mm tolerance)
- [ ] **Fit**: Pendant slides through with 0.5mm clearance all around

## Current Design Values

```python
# From designs/v1-charging-stand.py
TOL = 0.5                    # Print tolerance per side
OMI_W = 41 + TOL * 2        # 42mm pocket width  
OMI_H = 40 + TOL * 2        # 41mm pocket height
OMI_THICK = 13              # 13mm pendant thickness
OMI_CRADLE_DEPTH = 15       # 15mm pocket depth (13+2)
OMI_VERTEX_R = 3            # 3mm fillet radius
```

## If Fit is Wrong

**Too tight** (pendant doesn't fit):
- Increase `TOL = 0.75` (1.5mm total tolerance)

**Too loose** (pendant falls through):  
- Decrease `TOL = 0.25` (0.5mm total tolerance)

**Shape doesn't match**:
- Verify pendant measurements with calipers
- Check six-sided diamond vs pendant silhouette
- Consider custom shape adjustments

## What's Next

1. ✅ Verify fit with template
2. ✅ Confirm pocket depth accommodates 13mm thickness  
3. ✅ 3D print full charging stand
4. ✅ Test actual pendant charging alignment

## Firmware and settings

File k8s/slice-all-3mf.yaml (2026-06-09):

apiVersion: batch/v1
kind: Job
metadata:
  name: slice-all-3mf
  namespace: utilities
spec:
  ttlSecondsAfterFinished: 3600
  backoffLimit: 1
  template:
    spec:
      restartPolicy: Never
      nodeSelector:
        kubernetes.io/arch: amd64
      initContainers:
      - name: fetch-stls
        image: alpine/git:latest
        command: ["/bin/sh", "-c"]
        args:
        - |
          echo "=== Fetching STLs and 3MF converter ==="
          git clone --depth 1 https://github.com/somni-labs/somni-wearable-dock.git /tmp/repo
          cp /tmp/repo/output/v1-charging-stand-bottom-tray.stl /shared/bottom-tray.stl
          cp /tmp/repo/output/v1-charging-stand-top-tray.stl /shared/top-tray.stl
          cp /tmp/repo/output/v1-charging-stand-device-tray.stl /shared/device-tray.stl
          cp /tmp/repo/output/v1-charging-stand-mudra-pole.stl /shared/mudra-pole.stl
          cp /tmp/repo/output/v1-charging-stand-ipad-wall.stl /shared/ipad-wall.stl
          cp /tmp/repo/output/v1-charging-stand-ipad-cover.stl /shared/ipad-cover.stl
          cp /tmp/repo/output/v1-charging-stand-tilt-plate-uh.stl /shared/tilt-plate-uh.stl
          cp /tmp/repo/output/v1-charging-stand-tilt-plate-r1.stl /shared/tilt-plate-r1.stl
          cp /tmp/repo/output/v1-charging-stand-tilt-plate-omi.stl /shared/tilt-plate-omi.stl
          cp /tmp/repo/output/v1-charging-stand-push-rod-uh_ring.stl /shared/push-rod-uh.stl
          cp /tmp/repo/output/v1-charging-stand-push-rod-r1_ring.stl /shared/push-rod-r1.stl
          cp /tmp/repo/output/v1-charging-stand-push-rod-omi.stl /shared/push-rod-omi.stl
          cp /tmp/repo/output/v1-charging-stand-push-rod-mudra.stl /shared/push-rod-mudra.stl
          cp /tmp/repo/output/v1-charging-stand-servo-cam.stl /shared/servo-cam.stl
          echo "--- Fetching Qidi 3MF converter ---"
          git clone --depth 1 https://github.com/thelegendtubaguy/Qidi-3MF-Generator.git /shared/3mf-gen
          ls -la /shared/
          echo "=== Init complete ==="
        volumeMounts:
        - name: shared
          mountPath: /shared
      containers:
      - name: slicer
        image: cznewt/prusa-slicer:latest
        command: ["/bin/bash", "-c"]
        args:
        - |
          set -e
          echo "=== PrusaSlicer + Qidi 3MF — All Parts ==="
          echo "  Slices all parts with PETG profile, converts to .gcode.3mf,"
          echo "  validates, and uploads to Moonraker."
          echo ""

          SLICER=/prusa-slicer/prusa-slicer
          INI=/tmp/petg.ini
          MOONRAKER="http://192.168.1.15:7125"
          CONVERTER="/shared/3mf-gen/qidi_3mf_from_gcode.py"

          cat > "$INI" << 'PROFILE'
          layer_height = 0.3
          first_layer_height = 0.35
          perimeters = 3
          top_solid_layers = 5
          bottom_solid_layers = 4
          fill_density = 20%
          fill_pattern = gyroid
          perimeter_speed = 60
          external_perimeter_speed = 40
          infill_speed = 80
          solid_infill_speed = 60
          first_layer_speed = 20
          travel_speed = 180
          bridge_speed = 25
          gap_fill_speed = 30
          small_perimeter_speed = 30
          support_material = 1
          support_material_auto = 1
          support_material_spacing = 2
          support_material_angle = 0
          skirts = 2
          skirt_distance = 5
          brim_width = 3
          temperature = 240
          first_layer_temperature = 245
          bed_temperature = 85
          first_layer_bed_temperature = 85
          fan_always_on = 0
          min_fan_speed = 0
          max_fan_speed = 50
          bridge_fan_speed = 60
          overhangs_fan_speed = 50
          disable_fan_first_layers = 4
          gcode_flavor = klipper
          bed_shape = 0x0,275x0,275x295,0x295
          max_print_height = 265
          nozzle_diameter = 0.4
          retract_length = 1.2
          retract_speed = 30
          retract_lift = 0.2
          start_gcode = G28\nG1 Z5 F5000
          end_gcode = M400\nG91\nG1 E-5 F2700\nG1 Z10 F3000\nG90\nG1 X10 Y270 F6000\nM400\nM140 S0\nM104 S0\nM106 S0\nG4 P2000\nM84
          PROFILE

          # No-supports profile for device tray and accessories
          cp "$INI" /tmp/petg_nosupport.ini
          sed -i 's/support_material = 1/support_material = 0/' /tmp/petg_nosupport.ini
          sed -i 's/support_material_auto = 1/support_material_auto = 0/' /tmp/petg_nosupport.ini
          sed -i 's/brim_width = 3/brim_width = 0/' /tmp/petg_nosupport.ini

          sed -i 's/^[[:space:]]*//' "$INI"
          sed -i 's/^[[:space:]]*//' /tmp/petg_nosupport.ini
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

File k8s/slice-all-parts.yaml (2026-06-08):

apiVersion: batch/v1
kind: Job
metadata:
  name: slice-all-fixed
  namespace: utilities
spec:
  ttlSecondsAfterFinished: 3600
  backoffLimit: 1
  template:
    spec:
      restartPolicy: Never
      nodeSelector:
        kubernetes.io/arch: amd64
      containers:
      - name: slicer
        image: cznewt/prusa-slicer:latest
        command: ["/bin/bash", "-c"]
        args:
        - |
          set -e
          echo "=== PrusaSlicer — All 4 Parts (with gcode validation) ==="

          SLICER=/prusa-slicer/prusa-slicer
          INI=/tmp/pla_plus.ini
          MOONRAKER="http://192.168.1.15:7125"

          cat > "$INI" << 'PROFILE'
          # --- Print settings ---
          layer_height = 0.3
          first_layer_height = 0.35
          perimeters = 3
          top_solid_layers = 5
          bottom_solid_layers = 4
          fill_density = 20%
          fill_pattern = gyroid
          external_perimeter_speed = 40
          infill_speed = 60
          travel_speed = 150
          bridge_speed = 25
          support_material = 1
          support_material_auto = 1
          support_material_spacing = 2
          support_material_angle = 0
          skirts = 2
          skirt_distance = 5
          brim_width = 0

          # --- Filament settings (PLA+) ---
          temperature = 215
          first_layer_temperature = 220
          bed_temperature = 60
          first_layer_bed_temperature = 65
          fan_always_on = 1
          min_fan_speed = 100
          max_fan_speed = 100
          bridge_fan_speed = 100

          # --- Printer settings (QIDI Q2) ---
          gcode_flavor = klipper
          bed_shape = 0x0,275x0,275x295,0x295
          max_print_height = 265
          nozzle_diameter = 0.4
          retract_length = 0.8
          retract_speed = 40
          retract_lift = 0.2
          start_gcode = G28\nG1 Z5 F5000
          end_gcode = M400\nG91\nG1 E-5 F2700\nG1 Z10 F3000\nG90\nG1 X10 Y270 F6000\nM400\nM140 S0\nM104 S0\nM106 S0\nG4 P2000\nM84
          PROFILE

          sed -i 's/^[[:space:]]*//' "$INI"

          validate_gcode() {
            local FILE="$1"
            local REQUIRE_SUPPORTS="${2:-}"
            local ERRORS=0

            echo "  Validating $FILE..."

            # Check 1: Bed temperature — M140 or M190 with target >= 55
            local BED_TEMP
            BED_TEMP=$(grep -E '^M1[49]0 S[0-9]+' "$FILE" | sed 's/.*S\([0-9]*\).*/\1/' | head -1)
            if [ -z "$BED_TEMP" ] || [ "$BED_TEMP" -lt 55 ]; then
              echo "  FAIL: Bed temperature missing or too low (got: ${BED_TEMP:-none}, need >= 55)"
              ERRORS=$((ERRORS + 1))
            else
              echo "  OK: Bed temperature = ${BED_TEMP}C"
            fi

            # Check 2: Extruder temperature — M104 or M109 with target >= 210
            local EXT_TEMP
            EXT_TEMP=$(grep -E '^M10[49] S[0-9]+' "$FILE" | sed 's/.*S\([0-9]*\).*/\1/' | sort -n | tail -1)
            if [ -z "$EXT_TEMP" ] || [ "$EXT_TEMP" -lt 210 ]; then
              echo "  FAIL: Extruder temperature missing or too low (got: ${EXT_TEMP:-none}, need >= 210)"
              ERRORS=$((ERRORS + 1))
            else
              echo "  OK: Extruder temperature = ${EXT_TEMP}C"
            fi

            # Check 3: Support material (conditional)
            if [ "$REQUIRE_SUPPORTS" = "--require-supports" ]; then
              local SUPPORT_LINES
              SUPPORT_LINES=$(grep -c ';TYPE:Support' "$FILE" || true)
              if [ "$SUPPORT_LINES" -eq 0 ]; then
                echo "  FAIL: No support material found (;TYPE:Support missing)"
                ERRORS=$((ERRORS + 1))
              else
                echo "  OK: Support material present ($SUPPORT_LINES sections)"
              fi
            fi

            # Check 4: Layer count sanity (> 3 layers — catches empty/corrupt files
            # but allows thin parts like the 2mm iPad cover plate)
            local LAYER_COUNT
            LAYER_COUNT=$(grep -c ';LAYER_CHANGE' "$FILE" || true)
            if [ "$LAYER_COUNT" -lt 3 ]; then
              echo "  FAIL: Only $LAYER_COUNT layers — file may be corrupt or empty"
              ERRORS=$((ERRORS + 1))
            else
              echo "  OK: $LAYER_COUNT layers"
            fi
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

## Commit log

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2026-05-12 feat: two-part snap-fit design with cable management, Mudra L-pole, USB-C pass-throughs
    Major evolution of the charging stand design:
    - Split into bottom cable tray + top device tray with cantilever snap clips
    - Mudra Link elevated L-pole with flush charger pocket (rotated for wristband drape)
    - 14x9mm USB-C head pass-through holes through both trays
    - Cable organizer ribs, USB hub recess, rubber feet in bottom tray
    - G2 glasses case shelf, iPad vertical slot with back wall
    - All dimensions validated against QIDI Q2 245x255mm build plate
    [v1-charging-stand.py]
2026-05-12 feat: resize internal recess for slim 4-port USB-C wall charger
    The original 65×30×12mm recess assumed a passive USB-C "hub" sharing
    one upstream PD profile. That architecture can't independently charge
    6 wearables — each expects its own regulated port. Off-the-shelf
    multi-port USB-C chargers (e.g. UGREEN Nexode 65W) contain wall-AC
    circuitry and won't fit a 12mm-thick recess.
    Resize to 88×55×17mm under the G2 case shelf, sized for the class of
    slim flat 4-port USB-C wall chargers (e.g. BUDI 34W: ~83×44×14mm,
    1× USB-C PD + 1× USB-C + 2× USB-A, ≥30W total). Total wearable load
    is <30W (≤5W each), so this class has headroom for simultaneous
    charging of all 6 devices.
    - v1: bot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
    [v1-charging-stand.py]
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2026-05-13 feat: Update Omi DevKit 2 pocket to match real pendant dimensions (#2)
    * feat: update Omi DevKit 2 pocket to match real pendant dimensions
    Replace rounded triangle with six-sided diamond shape based on caliper measurements:
    - Width: 41mm (previously 72mm triangle)
    - Height: 40mm (previously estimated)
    - Depth: 13mm thick + 2mm margin = 15mm pocket depth
    - Shape: Six-sided diamond (short top facet + longer bottom point)
    - Direct charging via pogo pins (no separate charging dock)
    Changes:
    - New six_sided_diamond_points() function replaces equilateral_triangle_points()
    - Updated OMI_* parameters to match real pendant measurements
    - Pocket now sized for pendant itself, not oversized charging d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
    [omi_pocket_2d.dxf, omi_pocket_coordinates.csv, omi_pocket_profile.dxf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]
2026-05-13 feat: Update Mudra Link charger pocket to match real device dimensions (#3)
    * feat: Update Mudra Link charger pocket to match real device dimensions
    Updated pocket dimensions based on real caliper measurements:
    - Width: 20mm → 12mm (+tolerance) - was 8mm too wide
    - Length: 34mm → 30mm (+tolerance) - was 4mm too long
    - Height: 11mm → 8mm (+tolerance) - was 3mm too tall
    Optimized supporting structure for smaller charger:
    - Reduced pole width from 30mm to 22mm (still accommodates band)
    - Reduced pole depth from 22mm to 20mm
    - Reduced shelf length from 40mm to 36mm
    - Reduced shelf height from 16mm to 14mm
    - Reduced pole height from 90mm to 85mm (69mm clearance preserved)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
    [v1-charging-stand-bottom-tray.step, v1-charging-stand-bottom-tray.stl, v1-charging-stand-top-tray.step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]
2026-05-13 feat: Update Ultrahuman Ring Air dock pocket to match real device dimensions
    Updates dock dimensions based on actual caliper measurements:
    - Side length: 48mm → 39mm (-9mm, corrected oversizing)
    - Height: 16mm → 13mm (-3mm, matches measured depth)
    - Cradle depth: 12mm → 10mm (proportional adjustment)
    - Corner radius: 4mm (unchanged, appropriate for smaller size)
    Real measurements: 39×39×13mm square charging dock.
    Previous dimensions were estimated and too large.
    [v1-charging-stand.py]
2026-05-13 chore: Update exported STL/STEP files with corrected Ultrahuman Ring Air dimensions
    Generated files reflect the updated 39×39×13mm dock pocket dimensions.
    Ready for 3D printing validation with real device.
    [v1-charging-stand-bottom-tray.step, v1-charging-stand-top-tray.step, v1-charging-stand-top-tray.stl]
2026-05-13 feat(dock-8): update Even Realities R1 charger pocket with real measurements
    Updates R1 charger dimensions from estimated to measured values:
    - Diameter: 42mm → 45mm (measured from actual device)
    - Height: 14mm → 12mm (measured from actual device)
    - Updated design parameters in v1-charging-stand.py
    - Updated documentation comments with measured values
    - Removed "estimated" notation in README, marked as measured
    - Maintains TOL tolerance for proper fit
    This improves the precision of the charging cradle for better device fit
    and ensures the pocket is sized correctly for the actual R1 charger.
    Addresses DOCK-8: Update Even Realities R1 charger pocket with real measurements
    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
    [v1-charging-stand.py]
2026-05-13 feat(dock-9): update Even Realities G2 glasses case with real measurements
    Updates G2 case dimensions from estimated to measured values:
    - Width: 165mm → 170mm (+5mm for proper fit)
    - Depth: 70mm → 75mm (+5mm for actual case size)
    - Height: 35mm → 30mm (-5mm, more accurate profile)
    Also fixes G1/G2 model inconsistency in documentation:
    - Corrected device table to show G2 (matches design file)
    - Updated specification notes with measured values
    - Removed "estimated" notation, marked as measured
    Design changes:
    - Updated parametric dimensions in v1-charging-stand.py
    - Added measurement comments for future reference
    - Layout automatically adjusts via REAR_ROW_Y calculation
    - Maintains TO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
    [v1-charging-stand.py]
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2026-05-15 fix(dock-6): correct Omi pendant pocket to alternating 30/15mm edges
    The Omi DevKit 2 pendant is a six-sided diamond with 3 long edges (30mm)
    alternating with 3 short edges (15mm), not a regular hexagon. The previous
    geometry used a 7-vertex shape with equal-width sides. Now uses proper
    120° interior angles with edge-walking to produce the correct alternating
    edge lengths.
    [v1-charging-stand.py]
2026-05-17 fix(dock-8): correct R1 charger pocket to real caliper measurements
    Update Even Realities R1 circular charger pocket from incorrect values
    (45mm dia × 12mm) to actual measured dimensions (30mm dia × 10mm).
    R1_DIA: 45 → 30mm, R1_H: 12 → 10mm.
    [v1-charging-stand.py]
2026-05-17 feat(v1): device-specific USB cable routing for UH, R1, and Omi
    - Ultrahuman Ring Air: USB-C port faces rear (+Y). Added rear wall slot
    in pocket and moved floor pass-through to rear edge.
    - Even Realities R1: Fixed cable exits left edge of disc. Replaced
    centered USB-C hole with a thin cable groove on the left pocket wall.
    - Omi DevKit 2: USB-C port on left long side, offset ~8mm from corner.
    Moved pass-through to left-offset position with port slot in pocket wall.
    Bottom tray holes updated to match all three positions.
    [v1-charging-stand.py]
2026-05-17 fix(v1): Omi USB-C slot perpendicular to angled pocket wall
    The port slot was axis-aligned but the left long side of the diamond
    runs at 60°. Now the slot is rotated -30° (perpendicular to the edge)
    so the USB-C connector inserts straight into the angled wall. Position
    is 8mm from the v4 corner along Edge 4.
    [v1-charging-stand.py]
2026-05-17 fix(v1): remove duplicate cable pass-through holes in top tray
    The generic loop was cutting holes for UH, R1, and Omi that overlapped
    with the device-specific cuts in each cradle section. Now the generic
    loop skips those three devices since they have custom cable routing.
    [v1-charging-stand.py]
2026-05-17 fix(v1): size all cable holes for USB-C head feed-through
    All pass-through holes must be large enough for the USB-C connector
    head (14x9mm) to feed through during assembly — not just the cable.
    Fixed R1 floor hole (was 6x5, now 14x9) and R1 wall groove (was 5mm
    thin cable slot, now 14mm wide for head to pass during assembly).
    [v1-charging-stand.py]
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2026-05-17 fix(v1): update G2 glasses case to measured dimensions with wedge profile
    Caliper measurements replace old estimates:
    - G2_W: 165mm → 174mm (+9mm)
    - G2_D: 70mm → 66mm (-4mm)
    - G2_H: flat 35mm → wedge 50mm (tall) / 36mm (short)
    The cradle pocket is now a trapezoidal void (XZ trapezoid extruded along Y)
    with an angled floor that mirrors the case's 14mm taper, so the case sits
    flush on the stand. Stand width (240mm) still provides 65mm margin over the
    new 175mm pocket width.
    [v1-charging-stand-bottom-tray.step, v1-charging-stand-bottom-tray.stl, v1-charging-stand-top-tray.step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]
2026-05-17 feat(dock-11): update charger recess for VanBon Smart USB Charger
    Replace generic slim USB-C brick dimensions with real VanBon caliper
    measurements: 134×68×33mm. Raise SPLIT_Z to 40mm and STAND_H to 56mm
    so the 33mm-tall brick fits inside the bottom tray. Redirect the AC
    input cable slot to the left wall (−X), matching the charger's physical
    layout: AC input on the short left face, 8× USB-A ports on the long
    front face.
    [v1-charging-stand.py]
2026-05-17 fix(dock-11): fix cable slot gap and G2 pocket floor clearance
    Two geometry bugs found in double-check:
    1. Cable slot was centered on the outer wall face only, leaving a 50mm
    gap between it and the charger recess left edge. Replaced with a
    computed slot that bridges from the recess left face through the
    left wall so the AC cable has a continuous exit path.
    2. G2_CRADLE_DEPTH (18mm) exceeded TOP_H (16mm), meaning the pocket
    would punch through the top tray floor. Raised STAND_H to 61mm
    (TOP_H=21mm), giving 3mm of solid material below the G2 pocket.
    [v1-charging-stand.py]
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2026-05-19 feat(dock-10): update iPad slot for portrait 13" iPad Pro/Air
    Real measured dimensions are 267×213mm (portrait). Reduces IPAD_SLOT_W
    from 235mm (old landscape assumption) to 215mm (213mm + 2mm tolerance),
    updates comments to reflect portrait orientation, and adds a pytest suite
    asserting the slot is sized correctly for the measured device.
    [v1-charging-stand.py]
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2026-05-19 fix(export): translate STLs to build plate (Z=0) and flip top tray
    The top tray STL was exported at its assembly position (Z=40mm),
    causing the slicer to generate G-code that printed 40mm above the
    bed — extruding in midair. The export script now:
    - Translates both trays so Z_min = 0 (build plate)
    - Flips the top tray upside-down (180° around X) so pocket surfaces
    face the bed for best print quality
    - STEP files retain original assembly positions for CAD review
    [v1-charging-stand-bottom-tray.step, v1-charging-stand-top-tray.step, v1-charging-stand-top-tray.stl]
2026-05-20 fix(v1): resolve G2 pocket / iPad slot 20mm overlap collision
    The G2 glasses case depth shrank from 75mm to 66mm (PR #8), which
    shifted REAR_ROW_Y forward from 41.5 to 46.0. But the iPad slot
    position was unchanged, causing the G2 rear edge (Y=79.5) to overlap
    the iPad front edge (Y=59.5) by 20mm — merging both voids into a
    broken combined pocket.
    Fix: compute REAR_ROW_Y by centering the G2 case in the available
    gap between the front-row device rear edges and the iPad slot front
    edge. This gives 11mm clearance on both sides.
    Before: REAR_ROW_Y = STAND_D/2 - G2_D/2 - 8 = 46.0 (overlap!)
    After: REAR_ROW_Y = (front_rear + ipad_front) / 2 = 15.0
    Regenerated all STL and STEP output file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
    [v1-charging-stand-bottom-tray.step, v1-charging-stand-bottom-tray.stl, v1-charging-stand-top-tray.step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]
2026-05-20 fix(v1): increase stand depth 175→200mm for G2/wearable clearance (#12)
    The G2 glasses case (174×66mm) was only 11mm from the front-row
    wearable pockets — visually overlapping them in the viewer. Increasing
    STAND_D from 175 to 200mm gives 23.5mm clearance on both sides of the
    G2 case (to front-row wearables and iPad slot). Still fits the Q2
    build plate (240×200 vs 245×255mm limit).
    [v1-charging-stand.py]
2026-05-21 revert: restore G2 rear-row position and stand depth to working state (#13)
    PRs #11 and #12 broke the layout by pulling the G2 case 31mm forward
    (centering it between front row and iPad), then trying to compensate by
    enlarging the stand. The original formula `STAND_D/2 - G2_D/2 - 8` kept
    the G2 at the rear with 42mm clearance from front-row wearables — which
    was correct.
    Reverts STAND_D back to 175mm and REAR_ROW_Y to the original formula.
    [v1-charging-stand.py]
2026-05-21 revert: restore design to pre-PR8 baseline (5e8c853) (#14)
    Reverts all changes from PRs #8-#13 which progressively broke the
    design: G2 wedge profile (incorrect), VanBon charger height increase
    (38→61mm), iPad portrait switch, collision "fix" that pulled G2
    forward, and depth increase.
    Restores: STAND_H=38, SPLIT_Z=22, G2=170×75×30 flat box,
    original charger recess, landscape iPad slot.
    [v1-charging-stand.py]
2026-05-21 fix(v1): update G2 case to measured dimensions — 174×66×36mm flat box (#15)
    Caliper measurements: 174mm length, 66mm depth, 36mm height.
    Simple rectangular pocket (no wedge). Cradle is a shallow 18mm
    insert to hold the case in place, not a full enclosure.
    [v1-charging-stand.py]
2026-05-21 fix(v1): center G2 between front row and iPad to eliminate overlap (#16)
    The old formula (STAND_D/2 - G2_D/2 - 8) pushed the G2 rear edge to
    Y=79.5, overlapping the iPad slot front edge at Y=59.5 by 20mm.
    Now centers G2 between the front-row rear edge and iPad front edge,
    giving 11mm clearance on both sides. Stand depth stays at 175mm.
    [v1-charging-stand.py]
2026-05-21 feat(v1): cherry-pick USB-C cable routing from reverted PRs (#17)
    Cherry-picks 5 commits that add device-specific USB cable routing,
    which were lost when we reverted to the pre-PR8 baseline:
    - 3c3bec3: Device-specific cable routing (UH rear, R1 left groove, Omi left-offset)
    - fa7d65c: Omi USB-C slot rotated perpendicular to angled pocket wall
    - eba2c5f: Remove duplicate cable holes for UH/R1/Omi (custom routing)
    - 6bbeb73: Size all holes for USB-C head feed-through (14×9mm)
    - 3bab7cf: 2 auxiliary cable pass-throughs for spare charger ports
    [v1-charging-stand.py]
2026-05-21 fix(v1): move UH Ring cable exit to left (-X) for consistent routing (#18)
    All front-row devices now have cable openings on the same side (-X):
    - UH Ring: left wall slot (was rear +Y)
    - R1 Ring: left wall groove (unchanged)
    - Omi: left long side slot (unchanged)
    - Mudra: cable exits through pole toward -X (unchanged)
    Cleaner cable management with all cables routing in the same direction.
    [v1-charging-stand.py]
2026-05-21 fix: update charger recess to VanBon Smart USB Charger dimensions
    Replace placeholder slim charger (88×55×17mm) with actual measured
    VanBon Smart USB Charger dimensions (134×68×33mm + tolerance).
    Increase bottom tray height (SPLIT_Z 22→41mm) and total stand height
    (STAND_H 38→58mm) to accommodate the larger charger. AC cable now
    exits through the left wall (matching VanBon's short-side AC port),
    USB-A cable slots face forward toward device row.
    [v1-charging-stand-bottom-tray.step, v1-charging-stand-bottom-tray.stl, v1-charging-stand-top-tray.step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]
2026-05-21 redesign: zone-based bottom tray for intuitive charger placement
    Replace wall-to-wall rib grid with 3 clean zones:
    - Zone 1 (front): short ribs between device positions only, for cable routing
    - Zone 2 (center): completely open charger bay — VanBon drops straight in
    - Zone 3 (rear): minimal rib for iPad/AC cable separation
    The charger bay has corner retention tabs and no obstructions.
    Front spine rib has cable gaps at each device position for clean routing.
    [v1-charging-stand-bottom-tray.step, v1-charging-stand-bottom-tray.stl, v1-charging-stand-top-tray.step]
2026-05-21 fix: open charger bay with proper clearance for VanBon drop-in
    - Bay now cuts fully through tray top surface (open from above)
    - Removed corner tabs that blocked charger insertion (134x68 > 132x66)
    - Replaced with low-profile 5mm ledge strips for positioning
    - AC cable slot now full height through left wall
    - 5mm headroom above charger, 64mm cable channel in front for USB-A plugs
    [v1-charging-stand-bottom-tray.step, v1-charging-stand-bottom-tray.stl, v1-charging-stand-top-tray.step]
2026-05-21 fix: remove rear rib — keep USB port side completely open
    The VanBon's USB-A ports face the rear of the stand. Remove the
    rear zone rib so cables can be plugged in freely with no obstructions.
    [v1-charging-stand-bottom-tray.step, v1-charging-stand-bottom-tray.stl, v1-charging-stand-top-tray.step]
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2026-05-21 feat: cable loom posts, Velcro strap slots, and routing clips
    Redesign side pockets with proper cable management:
    - Staggered 2-column cable loom (5mm posts, 25mm tall, 22mm spacing)
    with offset columns so cables weave and grip naturally
    - Velcro strap through-floor slots (15x3mm) between post columns
    for cinching cable bundles with reusable Velcro strips
    - Storage bins (42x30mm) at rear of each pocket for adapters/dongles
    - Cable routing arch clips in front channel near each device position
    [v1-charging-stand-bottom-tray.step, v1-charging-stand-bottom-tray.stl, v1-charging-stand-top-tray.step]
2026-05-21 redesign: clear cable corridors + outer loom + Velcro throughout
    Split each side pocket into two zones:
    - Inner corridor (20mm, charger side): clear unobstructed path for
    cables routing from charger USB-A ports to front device holes
    - Outer loom (wall side): staggered winding posts for excess cable,
    with Velcro strap through-floor slots between columns
    Remove rear storage bins — they blocked cable paths. Add Velcro
    slots in the inner corridor too for cinching routed cables.
    Keep front channel arch clips near each device pass-through.
    Cable route: charger rear → side corridor → spine gap → front
    channel → arch clip → up through pass-through → device pocket.
    Co-Authored-By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
    [v1-charging-stand-bottom-tray.step, v1-charging-stand-bottom-tray.stl, v1-charging-stand-top-tray.step]
2026-05-21 fix: raised ribs with 12mm cable clearance for horizontal crossover
    All front channel ribs (cross ribs + spine rib) now float 12mm above
    the floor, creating open channels at the base where cables cross
    freely between device lanes in any direction. Spine rib gaps widened
    to 22mm and added at side corridor entrances so cables flow from
    charger → side corridor → under spine → across front channel → up
    to any device position without obstruction.
    [v1-charging-stand-bottom-tray.step, v1-charging-stand-bottom-tray.stl, v1-charging-stand-top-tray.step]
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2026-05-21 fix: make bottom tray open-top (remove ceiling)
    The bottom tray is now an open box with no ceiling. The top tray acts
    as the lid when snapped on. This makes the charger and cables fully
    accessible — just pop off the top tray, drop in the VanBon charger,
    route cables, and snap back together. Removed the now-unnecessary
    cable pass-through holes from the bottom tray (cables route freely
    through the open top into the top tray's pass-throughs).
    [v1-charging-stand-bottom-tray.step, v1-charging-stand-bottom-tray.stl, v1-charging-stand-top-tray.step]
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2026-05-21 fix: ensure Mudra pole cable channel is fully hollow
    Re-cut the vertical cable cavity and horizontal charger-to-post slot
    in world coordinates after the pole-to-base union. This guarantees
    the 14×12mm cable channel runs continuously from the bottom tray
    floor (Z=0) through the top tray slab, up the hollow post, and into
    the horizontal slot connecting to the charger bay on the shelf.
    [v1-charging-stand-bottom-tray.step, v1-charging-stand-top-tray.step, v1-charging-stand-top-tray.stl]
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2026-05-21 fix: iPad channel with solid floor, rail grooves, and slide-in cover
    Redesigned the iPad section with proper layered structure:
    - Solid floor (2.5mm) built into the top tray at Z=50, with a
    centered 18×14mm cable opening for USB-C feed-through
    - iPad channel cut above the floor (Z=52.5 to top surface)
    - Two continuous L-shaped rail grooves along front/back channel
    walls — cover plate slides in from either side
    - Cover plate (2mm) slides on rails, has 20mm cable notch
    - Hidden cable tunnel below the floor spans full width with exits
    on both side walls
    [v1-charging-stand-bottom-tray.step, v1-charging-stand-ipad-cover.step, v1-charging-stand-ipad-cover.stl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]
2026-05-21 feat: add K8s slicer job with gcode temp post-processing
    PrusaSlicer ignores filament temperatures from combined INI profiles.
    This job template slices all 3 parts (bottom tray, top tray, iPad
    cover) and post-processes the gcode with sed to inject correct temps:
    - M140 S65 / M190 S65 (bed: 65°C first layer)
    - M104 S220 / M109 S220 (extruder: 220°C first layer, 215°C after)
    - Proper end gcode to cool down and park
    [slice-all-parts.yaml]
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2026-05-22 fix: widen charger bay to account for ledge strip inset
    The charger bay cut was exactly charger size (138×72mm), but the 4mm
    ledge strips on each wall reduced the effective opening to 130×64mm —
    too small for the 134×68mm charger to drop past. Widened the bay cut
    to 146×80mm so the opening after ledges is 138×72mm (2mm clearance
    per side).
    [v1-charging-stand-bottom-tray.step, v1-charging-stand-bottom-tray.stl, v1-charging-stand-ipad-cover.step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]
2026-05-22 fix: increase device pocket tolerance from 0.5mm to 1mm per side
    FDM print tolerances at 0.5mm/side were too tight — same issue as the
    charger bay. Bumped TOL to 1.0mm for snug but removable drop-in fit
    across all device pockets (ring, R1, Omi, G2, Mudra charger).
    [v1-charging-stand-bottom-tray.step, v1-charging-stand-ipad-cover.step, v1-charging-stand-ipad-cover.stl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]
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2026-05-22 fix: replace sectioned INI with flat key=value format
    PrusaSlicer --load requires flat INI without [section] headers.
    The section headers caused silent fallback to defaults for all
    settings (bed temp 0C, supports off, etc). Remove fix_temps()
    workaround — no longer needed.
    [slice-all-parts.yaml]
2026-05-22 feat: add post-slice gcode validator
    validate_gcode() checks bed temp, extruder temp, layer count,
    coordinate bounds, and (optionally) support material presence.
    Aborts the slicer job before upload if any check fails.
    [slice-all-parts.yaml]
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2026-05-22 fix: use POSIX-compatible awk/sed in validate_gcode()
    The PrusaSlicer container has mawk (not gawk) and grep without
    Perl regex support. Replace GNU-only match() capture groups with
    split() on field separator, and grep -oP with grep -E + sed.
    [slice-all-parts.yaml]
2026-05-22 fix: bump layer height to 0.3mm for faster prints
    0.2mm was specified in the INI but never actually used (PrusaSlicer
    was ignoring the profile). Now that the flat INI is parsed correctly,
    0.2mm produces 41h prints. 0.3mm is appropriate for a functional
    charging dock and brings the top tray back to ~17h.
    [slice-all-parts.yaml]
2026-05-22 fix: lower layer count threshold from 10 to 3
    The iPad cover plate is only 2mm thick (6 layers at 0.3mm).
    The threshold of 10 was too strict for thin parts. 3 layers
    still catches empty/corrupt files while allowing legitimate
    thin geometry.
    [slice-all-parts.yaml]
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2026-05-22 feat: separate Mudra pole into standalone snap-in part
    - Add build_mudra_pole() with charger pocket, cable channels, and
    cantilever snap clips on base (prints upright, no supports)
    - Replace ~115 lines of inline pole construction in build_top_tray()
    with through-socket + snap engagement pockets
    - Wire up mudra pole build and cadquery-server preview display
    [v1-charging-stand.py]
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
